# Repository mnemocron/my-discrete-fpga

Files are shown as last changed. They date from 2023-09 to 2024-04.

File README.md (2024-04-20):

# Discrete 7400 logic based FPGA
A custom, modular FPGA architecture simulated in VHDL (GHDL), realized with discrete 7400-logic ICs, layouted on PCB with KiCAD and programmed through an abstraction layer via Arduino.

---

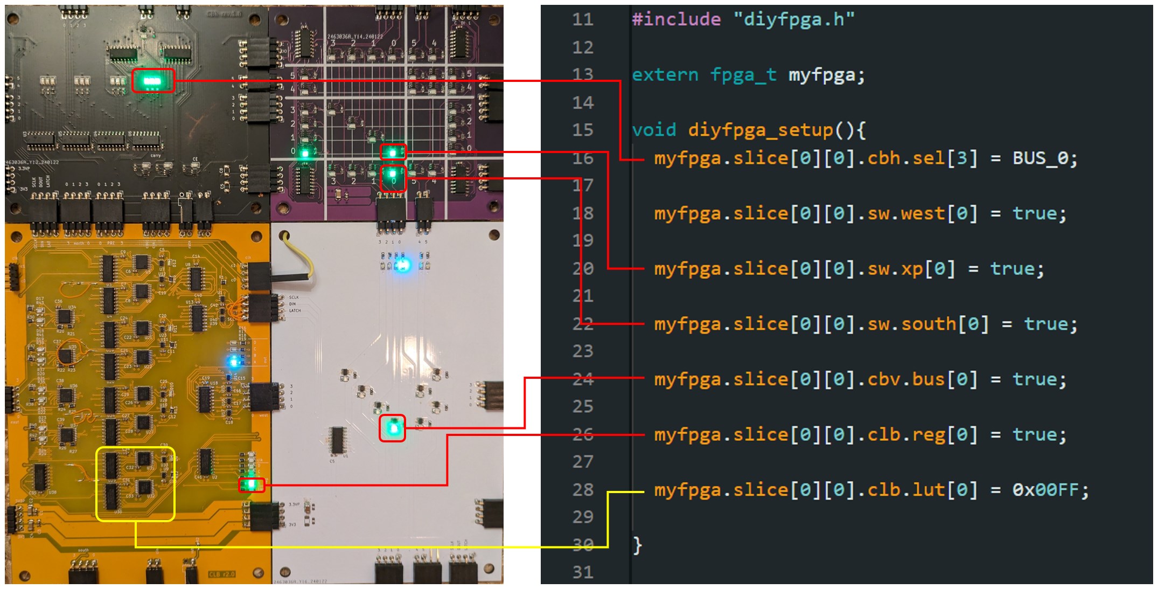
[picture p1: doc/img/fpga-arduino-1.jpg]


Read the full thorugh process and many explanations on my blog: 
[mnemocron.github.io](https://mnemocron.github.io/2023-12-08-DIY-FPGA-diary-0/)

## Motivation

> Why build arguably the worst FPGA ever?

Ever since building Ben Eaters [8 bit CPU](https://eater.net/8bit) myself, I wanted to build something even crazier.
The 8 bit CPU is arguably the worst CPU ever built - but it is a fantastic educational example.
And that is the case for the **4 bit FPGA**. It is a purely educational side project that boosted my knowledge about FPGA architecture, VHDL design and verification. Without further ado, here it is.

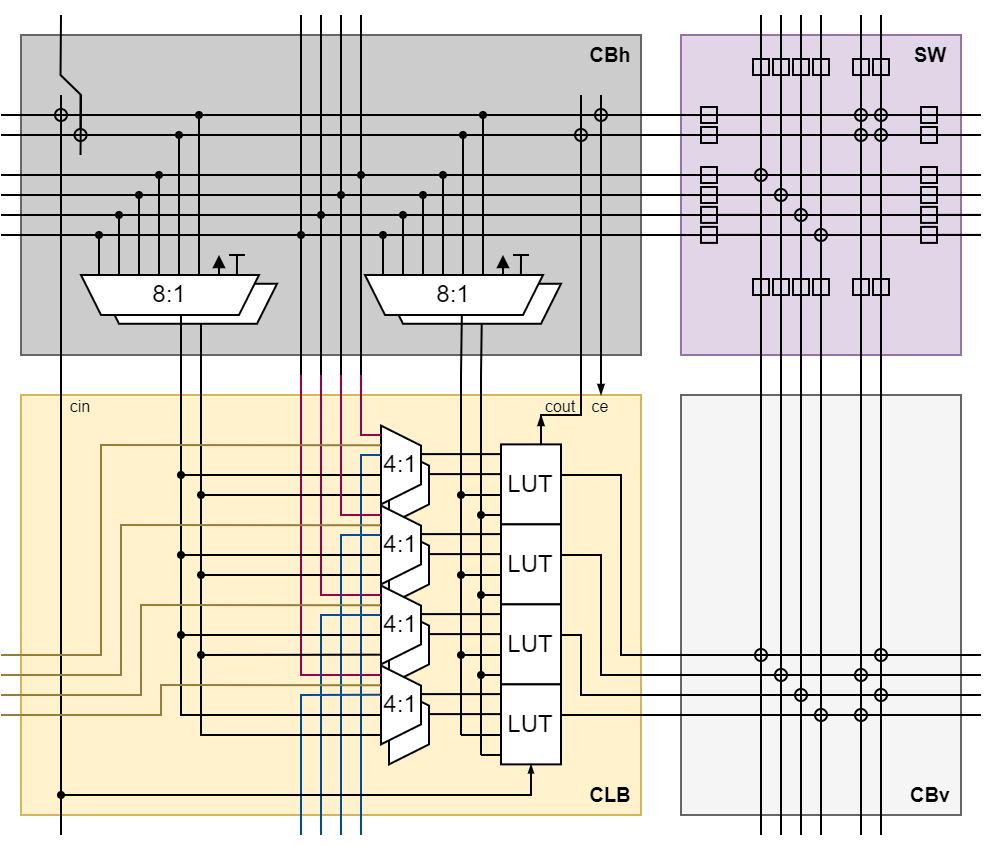
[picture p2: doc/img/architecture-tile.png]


## Build Process

The actual part list is WIP. Expected material cost are approximately 50 USD per assembled tile (4:4 bit LUT with interconnect).

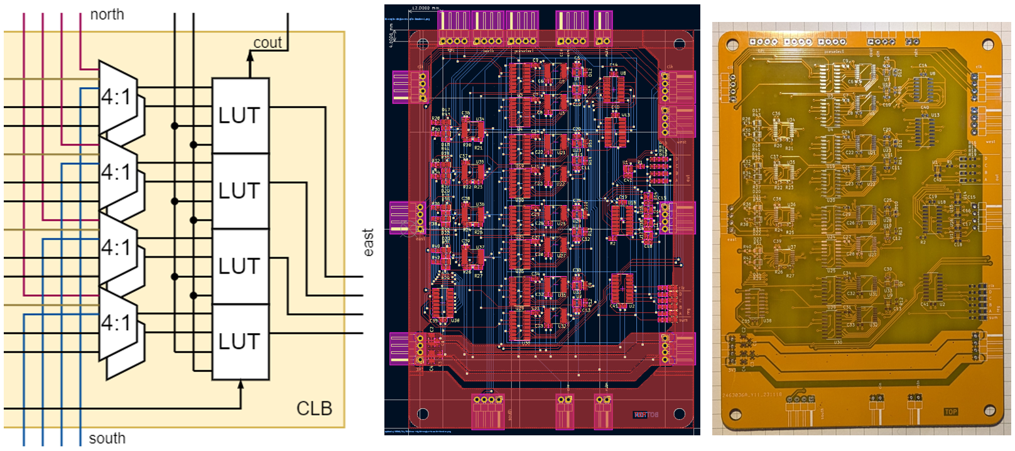
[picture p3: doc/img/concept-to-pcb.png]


---

## Start Here!

Do you want to build this FPGA yourself? Great! Everything, I made regarding this project is in this repository.

To understand the architecture start with `./architecture` or read about it on my blog.
Next, you may dive into the VHDL simulations in `./vhdl` and try out a few things.
Head straight to the `./vhdl/test` directory to see examples with the full FPGA architecture (instead of sub units).

- `./architecture` contains conceptual draw.io block diagrams
- `./doc` contains images, notes and tools that may be helpful
- `./ihdl` (WIP) contains ideas and concepts for a "compiler"
- `./kicad` contains **schematics and PCB files** for KiCAD 7.0
- `./sketch` contains Arduino code for testing of assembled PCB hardware and **abstraction layer in C**
- `./vhdl` contains models for 74xx ICs and the **full FPGA architecture for simulation**

---

## "Assemble" code to map onto the FPGA in Arduino

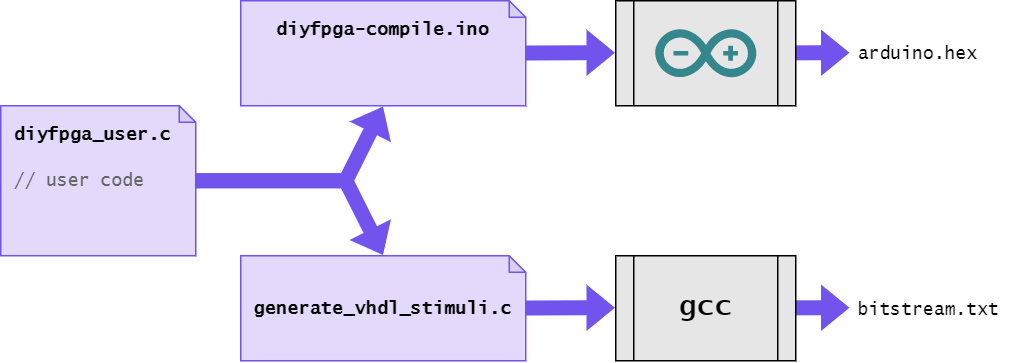
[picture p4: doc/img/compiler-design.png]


---

## Inspiration & Honorable Mentions

### Build an 8-bit computer from scratch

> I built a programmable 8-bit computer from scratch on breadboards using only simple logic gates. I documented the whole project in a series of YouTube videos and on this web site. Watch this video for an introduction:

on [eater.net](https://eater.net/8bit)

### Build your own FPGA

> Building a microcontroller or CPU out of discrete logic is a popular hobbyist pursuit, and it serves a useful purpose: building a CPU from scratch teaches you a lot about CPU architecture and tradeoffs; it's an interesting and instructive exercise. So, I wondered, wouldn't building an FPGA out of discrete logic be similarly educational? 

on [Nick's Blog](http://blog.notdot.net/2012/10/Build-your-own-FPGA)

on [Hackaday](https://hackaday.com/2012/11/01/discrete-fpga-will-probably-win-the-7400-logic-competition/)

### Princeton Regonfigurable Gate Array

> Build your own FPGA Chip or embedded FPGA IP with Python, and enjoy a fully open-source, auto-generated CAD flow specifically for your custom FPGA.

on [github](https://github.com/PrincetonUniversity/prga)

on [princeton.edu](http://parallel.princeton.edu/prga/)

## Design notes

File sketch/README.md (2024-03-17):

# Arduino Sketches 

to test the PCBs

for Arduino Uno

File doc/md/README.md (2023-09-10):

# 4 bit FPGA - Documentation

---

Immagine a gigantic array of breadboards. Each breadboard has a selection of digital circuit chips like XOR, AND and NOT gates plugged in, all waiting to be connected.
Whatever digital function we can come up with, we can map to those basic gates. And we can then use our bag of jumper cables to connect everything the way we need it to be.
That is an FPGA.
Except that the logic functions are look up tables (LUT) and the cables are the interconnect.
To make the timing of the signals deterministic, registers (D-type flip flops) are added to make it a clocked system.
That is all you need to build an FPGA: LUTs, interconnect and registers.

However, modern FPGA chips have many more features built in to implement frequently used digital operations more easily.
This ranges from the carry chain addon to LUTs, multiply-accumulate blocks (DSP slice) all the way to fully realized CPUs, AI cores and high-speed serial transceivers.

The first step in designing an FPGA is to have a sense of what applications might be realized on it.
It may require a CPU to do networking and graphical user interfaces or be targeted at radio frequency signal acquisition, processing and generation.
For this tiny FPGA project, a few applications should be able to run on it including:

- 4 bit or 8 bit counter
- 4 bit addition
- clock domain crossing

Nevertheless, the architecture shall remain modular to expand it with more features later on.
The initial architecture consists of:

- Configurable Logic Block (including the LUT)
- Interconnect blocks

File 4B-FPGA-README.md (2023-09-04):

# 4Bit-FPGA

---

## Application Use Cases

- 4-bit counter
- 4-bit counter with GPIO output
- 4-bit counter with 7-segment converter
- 4-bit counter with 7-segment hard-IP
- 4 + 4 bit adder from external GPIO input
- "roll a dice" with 2-clock domains, double flop synchronization, button press, and edge detection

something with RAM
- timer which stores counter value in BRAM, readout by cycle-clicking again
- toggle on RAM full/empty bits

CPU
- 

hard-IP
- BCD to 7-segment

cpu = custom instruction

### 4:1 CLB/LUT

4 bits is the ideal compromise for the planned application use cases.
4 bits are used in BCD numbering and is a reasonable amount for a counter application.

- clk_in[1:0]
- clb_in[3:0]
- clb_out

- conf_miso
- conf_mosi
- conf_sclk
- conf_ltch

conf bits
[15 :  0] = LUT content
[16] clk select

---

Shift Register 74HC595D
https://www.digikey.ch/de/products/detail/toshiba-semiconductor-and-storage/74HC595D/5879984

MUX 8:1 74HC151D
https://www.digikey.ch/de/products/detail/toshiba-semiconductor-and-storage/74HC151D/6198926

MUX 2:1 NC7SV157P6X
https://www.digikey.ch/de/products/detail/onsemi/NC7SV157P6X/1049166

D Flip-Flop 1 bit 74AHC1G79GW
https://www.digikey.ch/de/products/detail/nexperia-usa-inc/74AHC1G79GW-125/1229497

Signal Switch 1:1 
https://www.digikey.ch/de/products/filter/logik/signalumschalter-multiplexer-decoder/743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

https://www.digikey.ch/de/products/filter/schnittstelle/analoge-schalter-multiplexer-demultiplexer/747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

GPIO Buffer
https://www.digikey.ch/de/products/detail/toshiba-semiconductor-and-storage/74VHCV245FT/5977737

---

Videos

1. Breadboard FPGA Project overview

"the shittiest FPGA ever created"

DIY FPGA with 24 CLB-LUT

2. Configurable Logic Blocks - 4-bit FPGA
- basics of digital logic
- history of FPGAs
- configurable logic functions
- look up table
- SRAM bits as configuraion

3. Interconnect and Routing - 4-bit FPGA
- connecting the LUT
- freedom vs. complexity
- bit shift operation = "free"
- reference current modern FPGA switch boxes
- argument for architecture choice

4. I/O driver - 4-bit FPGA

4. Phase Locked Loop (PLL) - 4-bit FPGA
- clock generation and division

5. System Controller
- bitstream loading
- arduino board

6. Building the FPGA - 4-bit FPGA
- explain modern FPGA architecture (columns)
- 

7. Programming the Field Programmable Gate Array - 4-bit FPGA
- bitstream modification
- upload of bitstream

### Applications

1. Test Application: 4-bit counter - 4-bit FPGA
- 4-bit counter LUT programming
- interconnect routing
- GPIO configuration
- BCD to 7-segment decoder
- change to 8-bit
- explain why 8-bit CPU is "impossible"
- explain the scale and cost of this platform

2.

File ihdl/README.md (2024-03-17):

# iHDL Language Specification

---

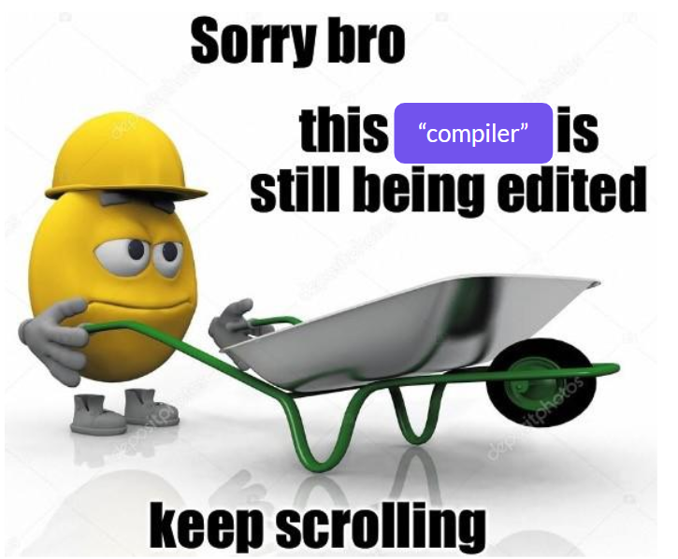
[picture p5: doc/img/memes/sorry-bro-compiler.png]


---

## General Rules

### Assignments

#### Static Assignment `:=`

`<var> := <const>;`

Assigning location properties or other static features that can be enabled or disabled.

Example, location constraint:
> `loc := "A1";`

#### Synchronous Assignment `<=`

`<port> <= <expr>;`

Synchronous assignment of a boolean function of input ports to an output port.
Using the synchronous assignment will evoque a D-type flip flop in the output signal to the specified port.

Example,
> `q0 <= b0 and b1;`

#### Asynchronous Assignment `

`<port> = <expr>;`

Asynchronous assignment of a boolean function of input ports to an output port.
Using the asynchronous assignment will output the evaluated signal directly to the specified port without a register stage.

Example,
> `q0 = b0 and b1;`

---

## Objects

The following objects can be instantiated.

### CLB Slice `slice`

#### Input Ports

- bus inputs (north) `b0`,`b1`,`b2`,`b3`
- sum inputs (north) `n0`,`n1`,`n2`,`n3`
- sum inputs (south) `s0`,`s1`,`s2`,`s3`
- lut expansion inputs `x0`,`x1`,`x2`,`x3`
- highway inputs (north) `h0`,`h1`

#### Output Ports

- bus outputs (east) `b0`,`b1`,`b2`,`b3`
- highway outputs (east) 

#### Internal signals

The following signals are optional to be assigned to the highway signals `h0` and `h1` when using the slice in the adder mode.

- sum carry input `cin`
- sum carry output `cout`

#### Options

- location constraint `loc`
- 

#### Operators

Valid operators are
- `and`
- `or`
- `not`
- `xor`
- `+` (arithmetical sum)

Valid values besides inputs are 
- `0` zero / GND
- `1` one / Vcc

## Error Types

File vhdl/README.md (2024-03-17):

# VHDL Simulation
---

## Run Simulation

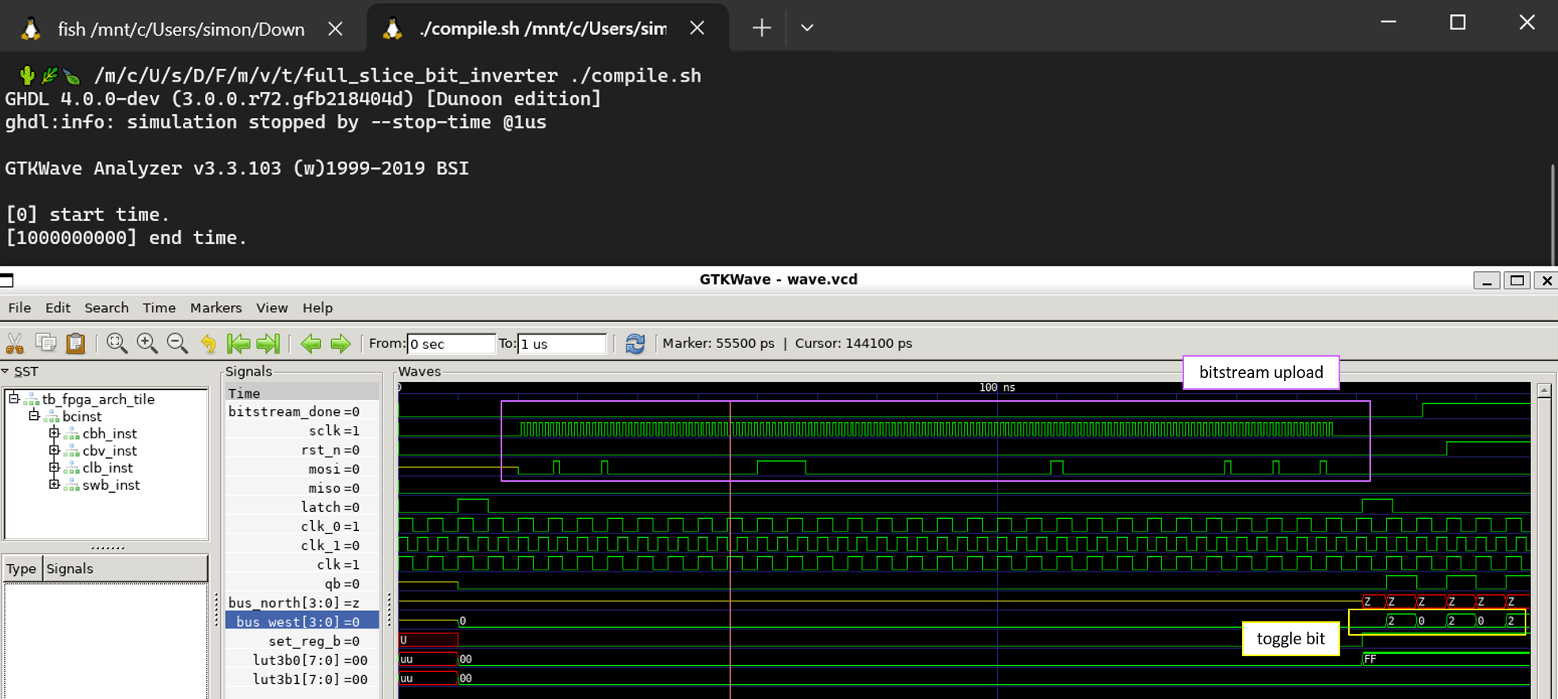
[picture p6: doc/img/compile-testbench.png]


The VHDL simulation consists of separate modules/units/entities for each 74xx chip.
Using the 74xx models, the higher level CLB, CBh, CBv and SW entities can be constructed.
Those four (CLB, CBh, CBv, SW) form the top level entity: a tile (`arch_tile`) which is one modular building block of the FPGA.
Multiple tiles in a 2D matrix form the full FPGA - this is not yet implemented in simulation.

Each entity folder contains a `compile.sh` which runs the unit testbench and opens GTKWave to inspect the waveform.
The testbenches are not self-checking although some of them contain assert statements.

This codebase was tested with the following setup:
- GHDL 4.0.0-dev (3.0.0.r72.gfb218404d)
- GTKWave Analyzer v3.3.103
- on Windows 10 WSL2 (Ubuntu 20.04.6 LTS focal on Windows 10 x86_64)

---

## FPGA modules

### Arch Slice (top level)

- Entity: `arch_slice`
- Dependencies: 
	+ `clb_slice`
	+ `sw_box`
	+ `connection_box_horizontal`
	+ `connection_box_vertical`
- Version: ``
- Tests: 
- Comments: see the `/tests` directory for various bitstreams that are uploaded to the `arch_slice` testbench

### CLB

- Entity: `clb_slice`
- Dependencies: 
	+ `sr_74xx595`
	+ `ff_74xx175`
	+ `mux_74xx151`
	+ `mux_74xx153`
	+ `mux_74xx157`
	+ `mux_74LVC1G157`
	+ `xor_74xx86`
- Version: `1.0.0`
- Tests: ✅
- Comments: simple tests only

### CBv

- Entity: `connection_box_vertical`
- Dependencies: 
	+ `sr_74xx595`
	+ `cbox`
- Version: `1.0.0`
- Tests: ✅
- Comments: only checking for multiple drivers inside entity itself

### CBh

- Entity: `connection_box_horizontal`
- Dependencies: 
	+ `sr_74xx595`
	+ `cbox`
	+ `mux_74xx151`
- Version: `1.0.0`
- Tests: -
- Comments: no self checking testbench

### SW box

- Entity: `sw_box`
- Dependencies: 
	+ `sr_74xx595`
	+ `digital_switch`
	+ `newsw`
- Version: ``
- Tests: -
- Comments: 

---

### MUX 8:1 74xx151 / 74xx251
- Single 8-Input Multiplexer
- for LUT3 elements

### MUX 4:1 74xx153 / 74xx253
- Dual 4-Input Multiplexer
- CLB tile input[3:2] select

### MUX 2:1 74xx157 / 74xx257
- Quad 2-Input Multiplexer
- sum output selector (`set_sum`)

### MUX 2:1 74-1G157
- Single 2-Input Multiplexer
- LUT4 element, set_reg, carry_mux

### D-type Register 74xx175
- Quad D-type Flip Flop

### XOR 74xx86
- Quad 2-Input XOR
- sum

### Shift Register 74xx595
- 8-bit shift register with latch
- LUT3 memory, configuration registers

---

| IC | simulation |
|:---|:---|
| 74xx157 | ✅ |
| 74xx153 | ✅ |
| 74xx151 | ✅ |
| 74xx175 | ✅ |
| 74xx595 | ✅ |
| 74xx86  | ✅ |
| 74_1G157 | ✅ |

---

## Interconnect Simulation

- use `std_logic` not `std_ulogic` because of "multiple drivers"

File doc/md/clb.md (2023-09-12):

# Configurable Logic Block (CLB)

---

A look up table has to have at least 2 inputs and one output.
To create more useful functions, more inputs are added.
One could create a LUT with 16 inputs to cover logic operations that depend on up to 16 input variables.
Such functions are rare and many of the inputs (and subsequently area on the silicon) would be wasted.
There is a balance regarding the maximum number of inputs which is somewhere between 4 and 6 inputs.
Various FPGA vendors have different approaches to it.

## Number of Inputs / Outputs

The number of outputs is usually 1. Some vendors however allow a 6:1 LUT to be configured as a 5:2 LUT instead, offering 2 outputs taking the same 5 signals as inputs.
This FPGA does not have a configurable number of outputs.
It would increase the complexity of the output routing and interconnect.

## CLB Architecture

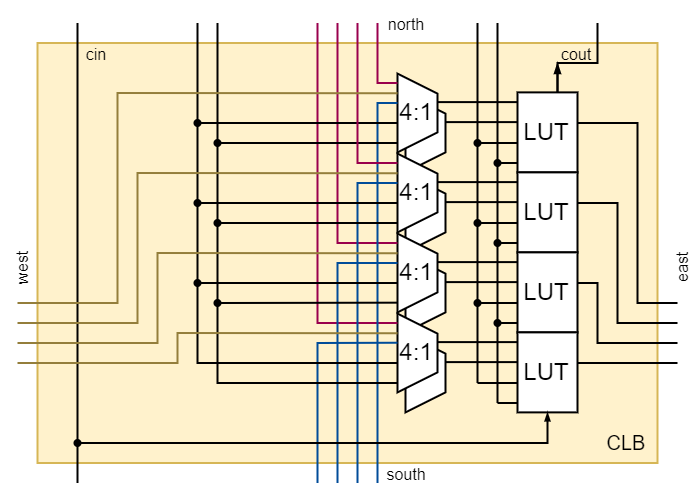
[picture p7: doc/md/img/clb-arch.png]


### Look Up Table (LUT) 

#### LUT3 / LUT4

To create useful applications within a reasonable usage of hardware area a 4 input LUT is proposed.
LUTs are most effectively implemented using a multiplexer which uses the LUT input signals as the address signals.
Since `2^4` input multiplexers are less common than `2^3` input multiplexers, the LUT4 is composed of two LUT3 primitives.
Here, a feature that configures the LUT4 (4:1) into a 2 output LUT3 (3:2) could be implemented. 
However, since there are 4 LUT4 instances in one CLB and because the output bus architecture only has 4 signals it makes no sense to have 8 outputs per CLB.

#### LUT Bundle (Slice / Block)

Multiple LUTs are usually bundeled within a block that is then called a configurable logic block (CLB).
(Sometimes LUTs are bundeled in slices and slices are bundeled in a block)
The CLB adds additional features and configurable options between the LUTs inside that block.
The most common feature is the carry chain.
One feature that is added to this FPGA is the carry chain.

### Connection Ports

The CLB requires input ports and output ports. 
A helpful simplification in the overall FPGA architecture is to define a direction in which the signals travel.
In this FPGA it is from west to east and in a weaker sense from north to south.

The CLB has four bus input ports:
- 4 bit bus north
	+ this is one of the 4 bit inputs for the adder mode
- 4 bit bus south
	+ this is one of the 4 bit inputs for the adder mode
- 4 bit bus west
	+ this bus is the direct output of the west CLB
- 4 bit preselected input
	+ each bit is preselected to any one signal of the bus
	+ allows for bit position changes (shift / rotate / flip)

The CLB has one 4 bit output port.

The CLB has 2 carry in signals and one carry out signal.
- North `cin` 
	+ can be activated in the north connection box
- South `cin` 
	+ can be activated in the north connection box of the south CLB

### Input Multiplexers 4:1 (post select) `insel*`

Under normal circumstances, all 4 LUTs inside the CLB receive the same 4 (preselected) input signals.
Depending on the individual LUT configuration, 4 different output signals are possible.
When performing the addition operation, this configuration of inputs is insufficient since it only allows for 2 + 2 bit additions.
Therefore, each LUT has 2 4:1 multiplexers before their `A2` and `A3` inputs.

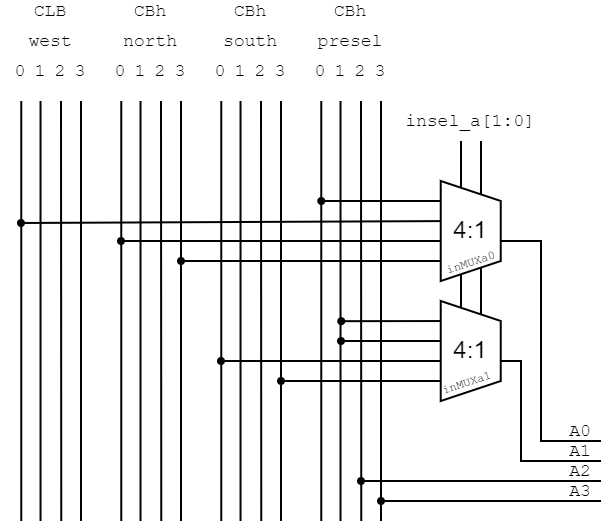
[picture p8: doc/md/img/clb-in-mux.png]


The 4-way input multiplexers have 4 modes.

| `insel_*[1:0]` | mode |
|:---|:---|
| `00` | regular preselect input `INMODE_PRESEL` |
| `01` | expanded LUT input `INMODE_EXPIN` |
| `10` | sum mode `INMODE_SUM` |
| `11` | sum mode bit reversed `INMODE_SUM_REVERSE` |

### Carry Look Ahead Adder

Performing additions in hardware requires a number of one bit full-adder circuits equal to the bit length of the largest number to be added.
A regular full adder can add 1 + 1 bits + 1 carry bit.
The carry bit is propagated from the LSB to the MSB.
A calculation is complete when the MSB of the sum is calculated which can only happen after the previous bits have ben sequentially calculated.

One way this could have been implemented is shown in the following picture.
It has been implemented this way in the other discrete FPGA on [Nick's Blog](http://blog.notdot.net/2012/10/Build-your-own-FPGA).
The LUT would be configured in a dual 3:2 LUT (instead of the regular 4:1) where one output is the sum output and the other output is the propagated carry.
This solution complicates the input multiplexin would add another 2:1 multiplexer to the proposed architecture draft.

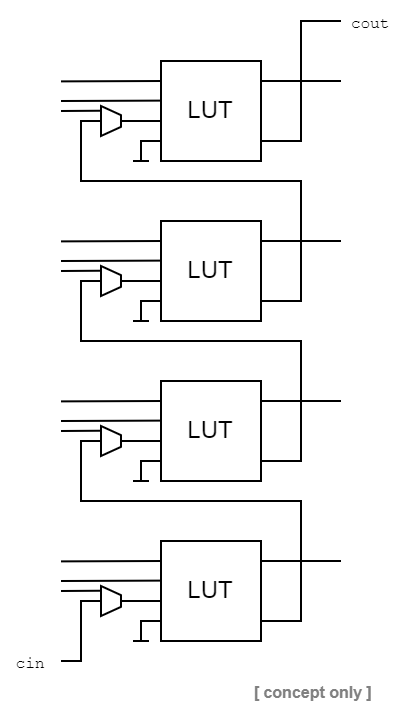
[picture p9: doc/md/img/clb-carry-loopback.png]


There is one substantial drawback when using long carry chains. 
The carry chain is the (timing) critical path.
For FPGAs there exist improvements to this problem to improve (timing) performance.
Xilinx FPGAs solve the critical path problem using a __Carry Look Ahead Adder__ as shown in the next picture. 
The carry bit is calculated in advance and selected based on the result of the current sum bit.

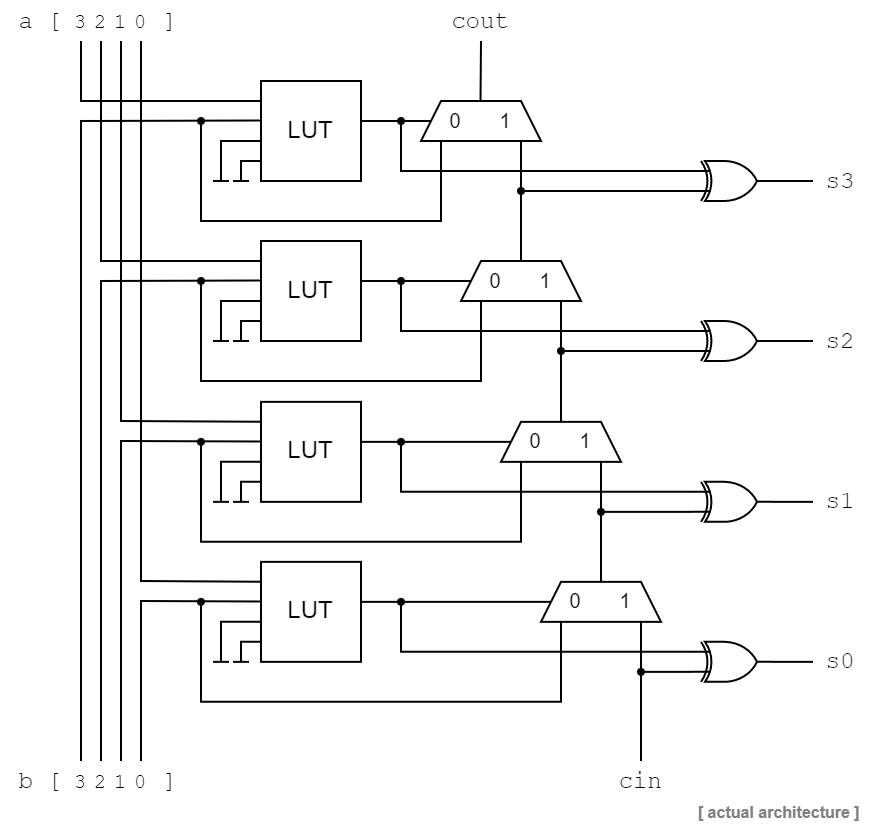
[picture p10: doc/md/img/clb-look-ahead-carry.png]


An example calculation of `13 + 5 = 18` is shown in the following figure.

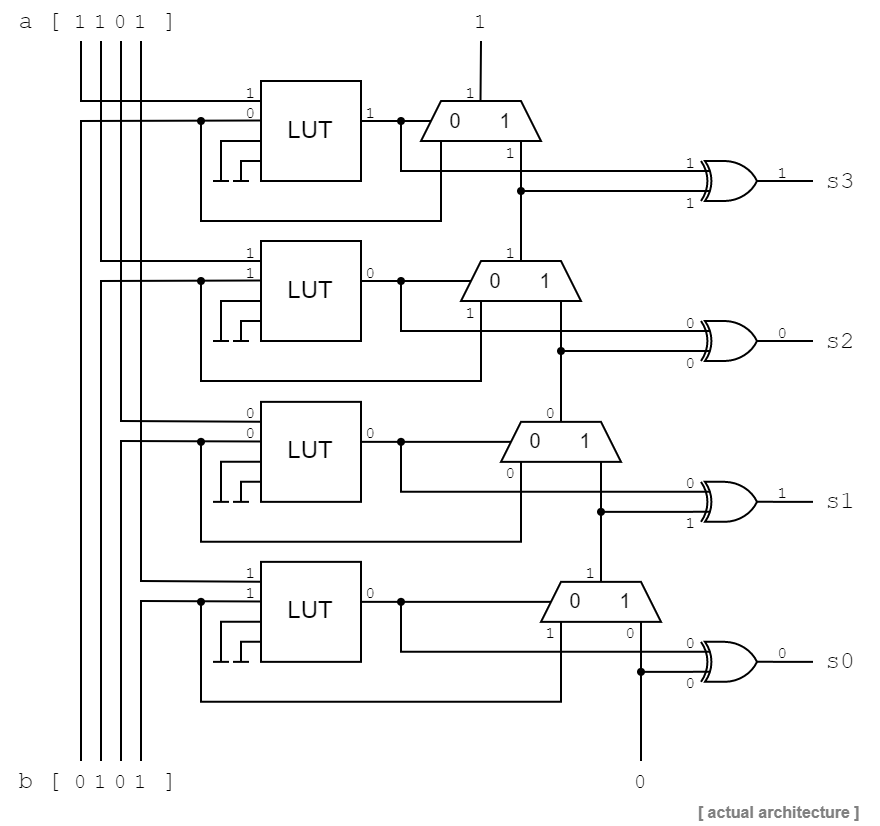
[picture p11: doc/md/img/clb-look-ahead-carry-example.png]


### Final LUT4 Architecture

The implemented LUT4 architecture is shown below. It features:
- LUT4 composed of 2x LUT3 instances
- __look ahead carry__ (optional sum mode)
- 4:1 input options for 2 of the 4 inputs
- optional output register (D-type flip flop)

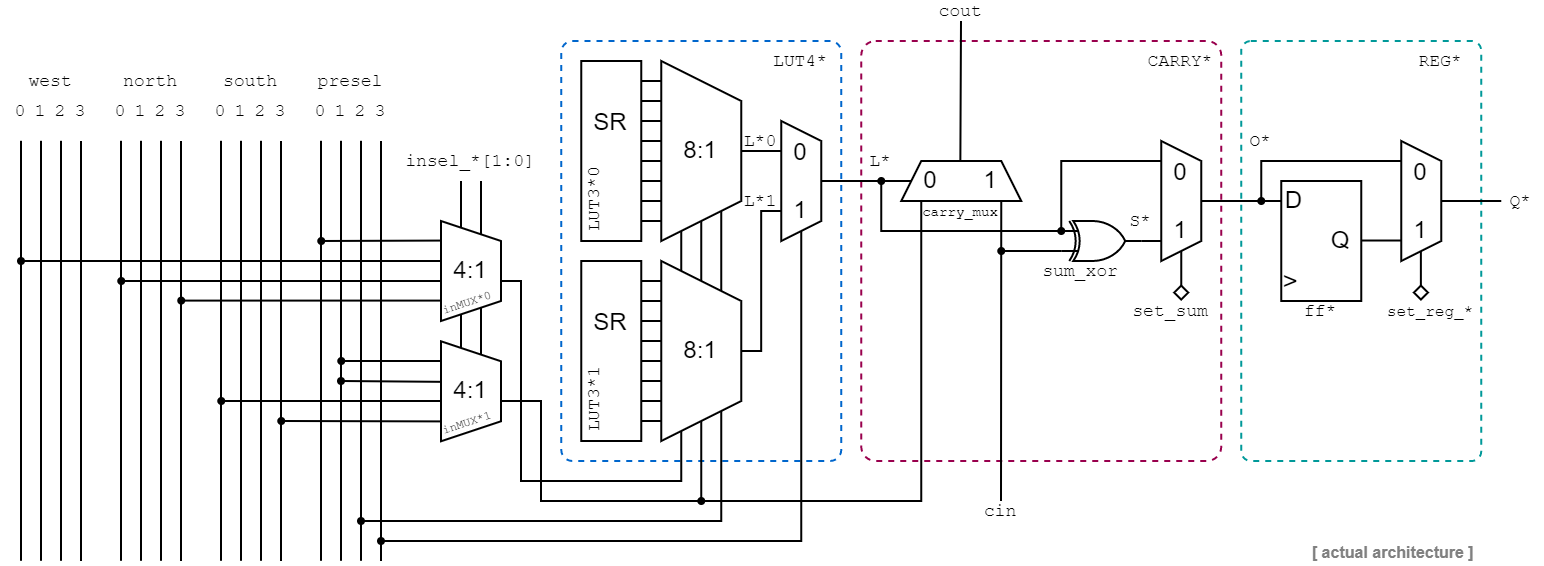
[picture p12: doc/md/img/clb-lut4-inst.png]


---

## 74** Part List

- `74**151`/ (`74**251` with tri-state output)
	+ single 8-input multiplexer
- `74**595`
	+ 8 bit shift register with latch
	+ used as one LUT3 memory
	+ used as configuration memory
- `74**153` / (`74**253` with tri-state output)
	+ dual 4-input multiplexer
	+ used as input selector
- `74**86`
	+ quad 2-input XOR
	+ used for sum calculation
- `74**157` / (`74**257` with tri-state output)
	+ quad 2-input multiplexer
	+ used for the LUT4 output selection (LUT output vs. sum output)
- `74**175`
	+ quad D-type flip flop
- `74**1GG157`
	+ single 2-input multiplexer
	+ used to combine 2x LUT3 instances to LUT4
	+ used for carry chain

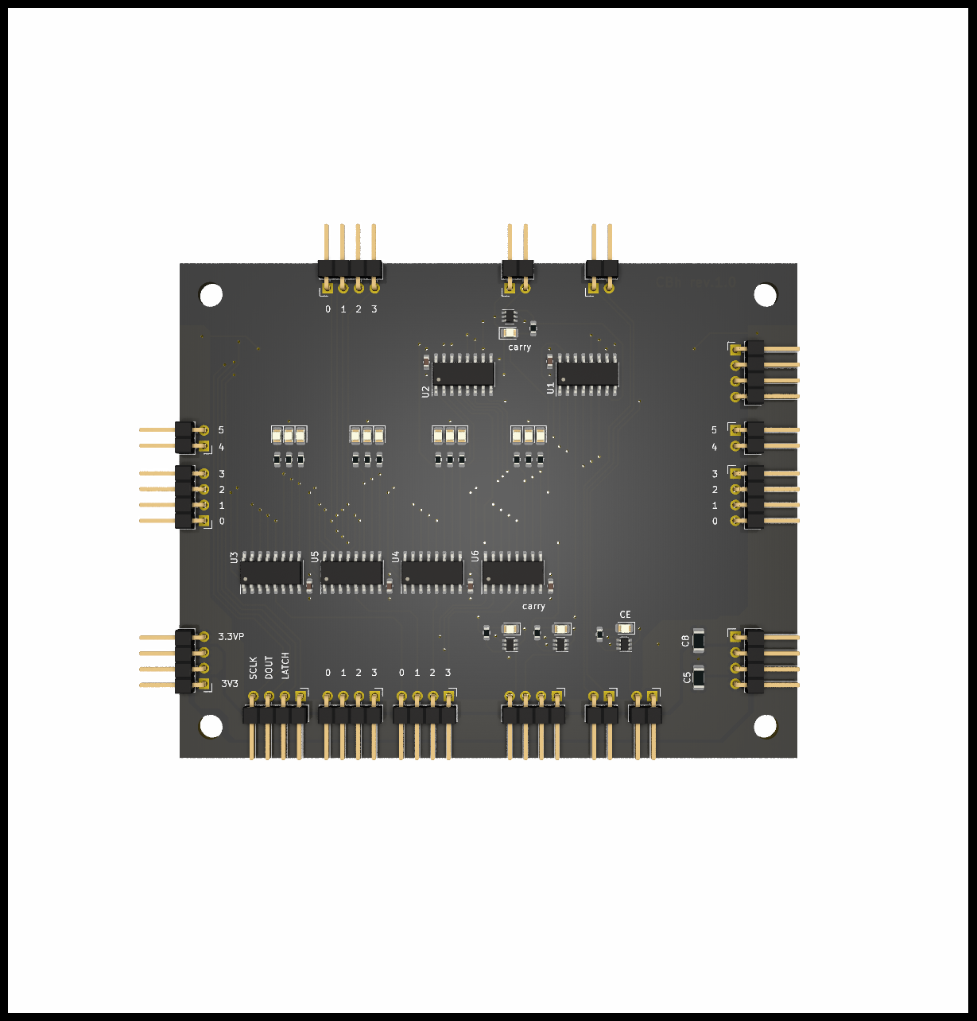
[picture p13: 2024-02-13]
doc/img/render/myFPGA-CBh.png

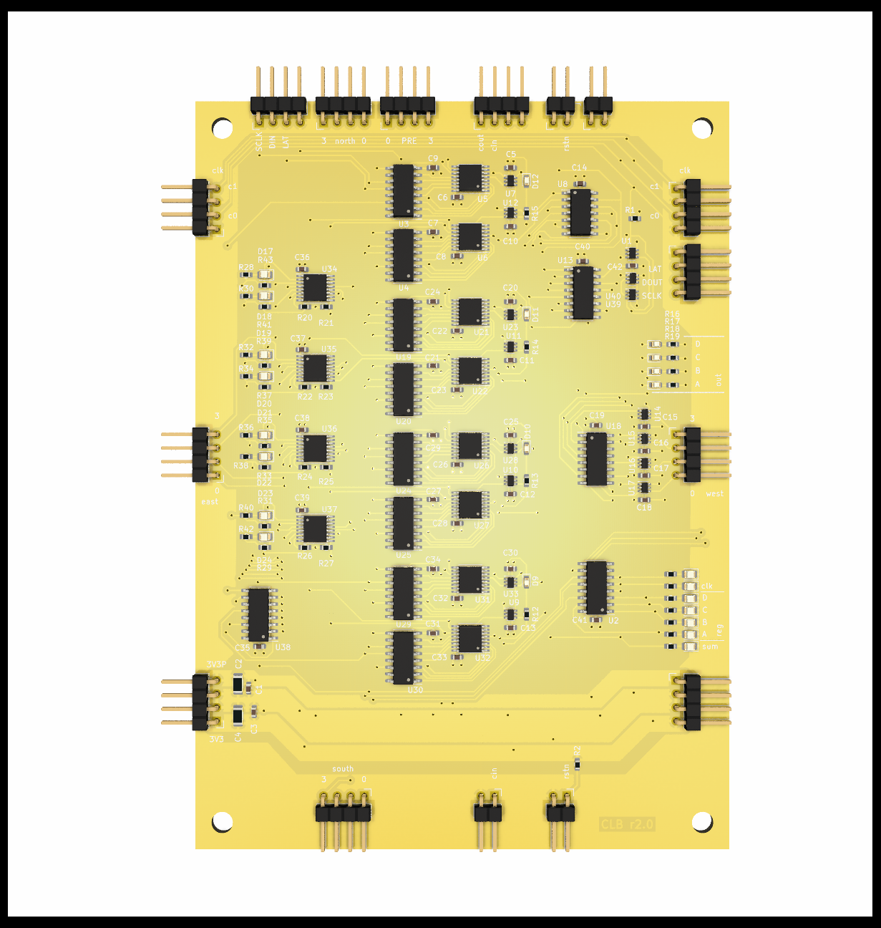
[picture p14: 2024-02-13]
doc/img/render/myFPGA-CLB-slice.png

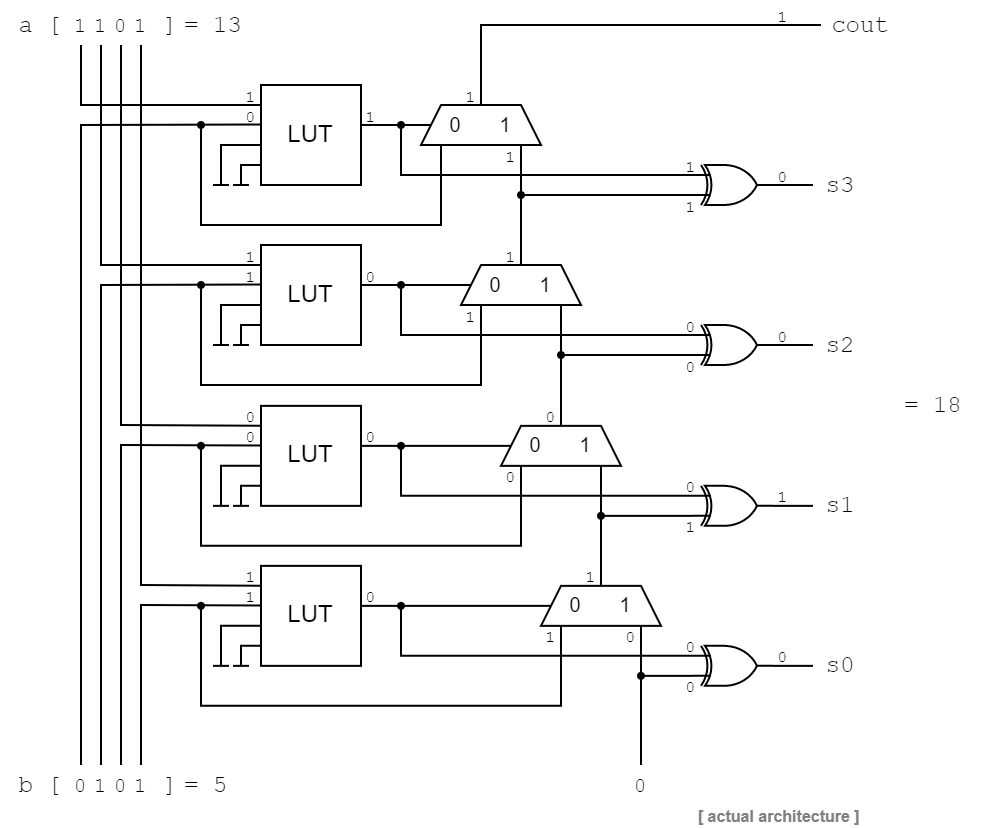
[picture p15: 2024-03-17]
doc/img/clb-look-ahead-carry-example.png

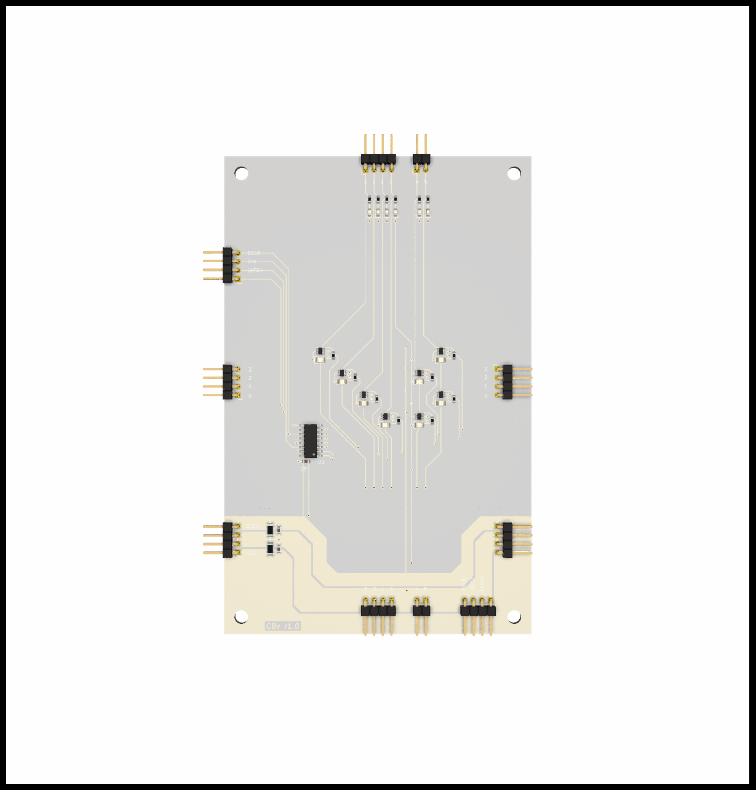
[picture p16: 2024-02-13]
doc/img/render/myFPGA-CBv.png

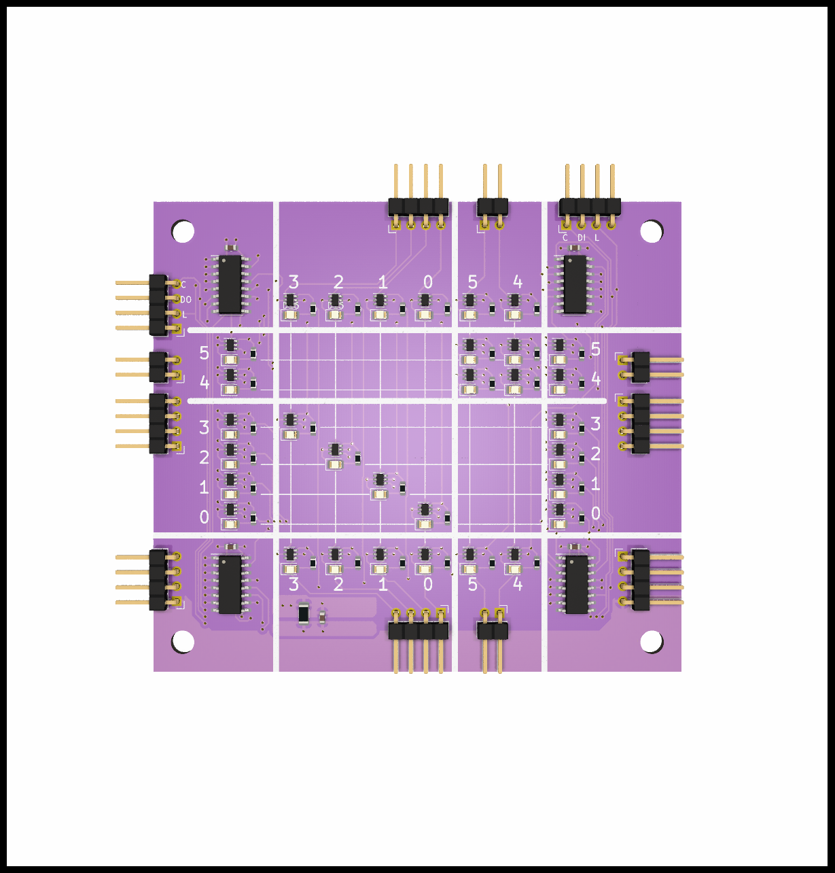
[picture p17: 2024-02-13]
doc/img/render/myFPGA-SW-box.png

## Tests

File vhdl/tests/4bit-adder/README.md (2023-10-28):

# Simple Bit Inverter

---

using LUT B

will output `clb_slice.Qb` --> `connection_box_vertical.bus_west[1]`

- `connection_box_vertical.xpoint_1_en = 1` (6)

will output `connection_box_vertical.bus_north[1]` --> `sw_box.bus_south[1]`

- `sw_box.sw_9 = 1` (126)
- `sw_box.sw_17 = 1` (118)
- `sw_box.xpoint_1 = 1` (134)

will output `sw_box.bus_west[1]` --> `connection_box_horizontal.bus_east[1]`

let's just pick preselect 2 and leave all other preselect to 0 (GND).

- `connection_box_horizontal.presel_2[0] = 0` 
- `connection_box_horizontal.presel_2[1] = 1` (93)
- `connection_box_horizontal.presel_2[2] = 1` (94)

will output `sw_box.preselect[2]` --> `clb_slice.cb_pre[2]`

`presel[2]` affects the LUT3 stage. implement an inverter where all other inputs are `X` (don't care)

- `insel`

- `LUT3b1[0] = 1` (52)
- `LUT3b1[1] = 1` (53)
- `LUT3b1[2] = 1` (54)
- `LUT3b1[3] = 1` (55)

- `LUT3b0[0] = 1` (44)
- `LUT3b0[1] = 1` (45)
- `LUT3b0[2] = 1` (46)
- `LUT3b0[3] = 1` (47)

- `set_reg_b = 1` (76)

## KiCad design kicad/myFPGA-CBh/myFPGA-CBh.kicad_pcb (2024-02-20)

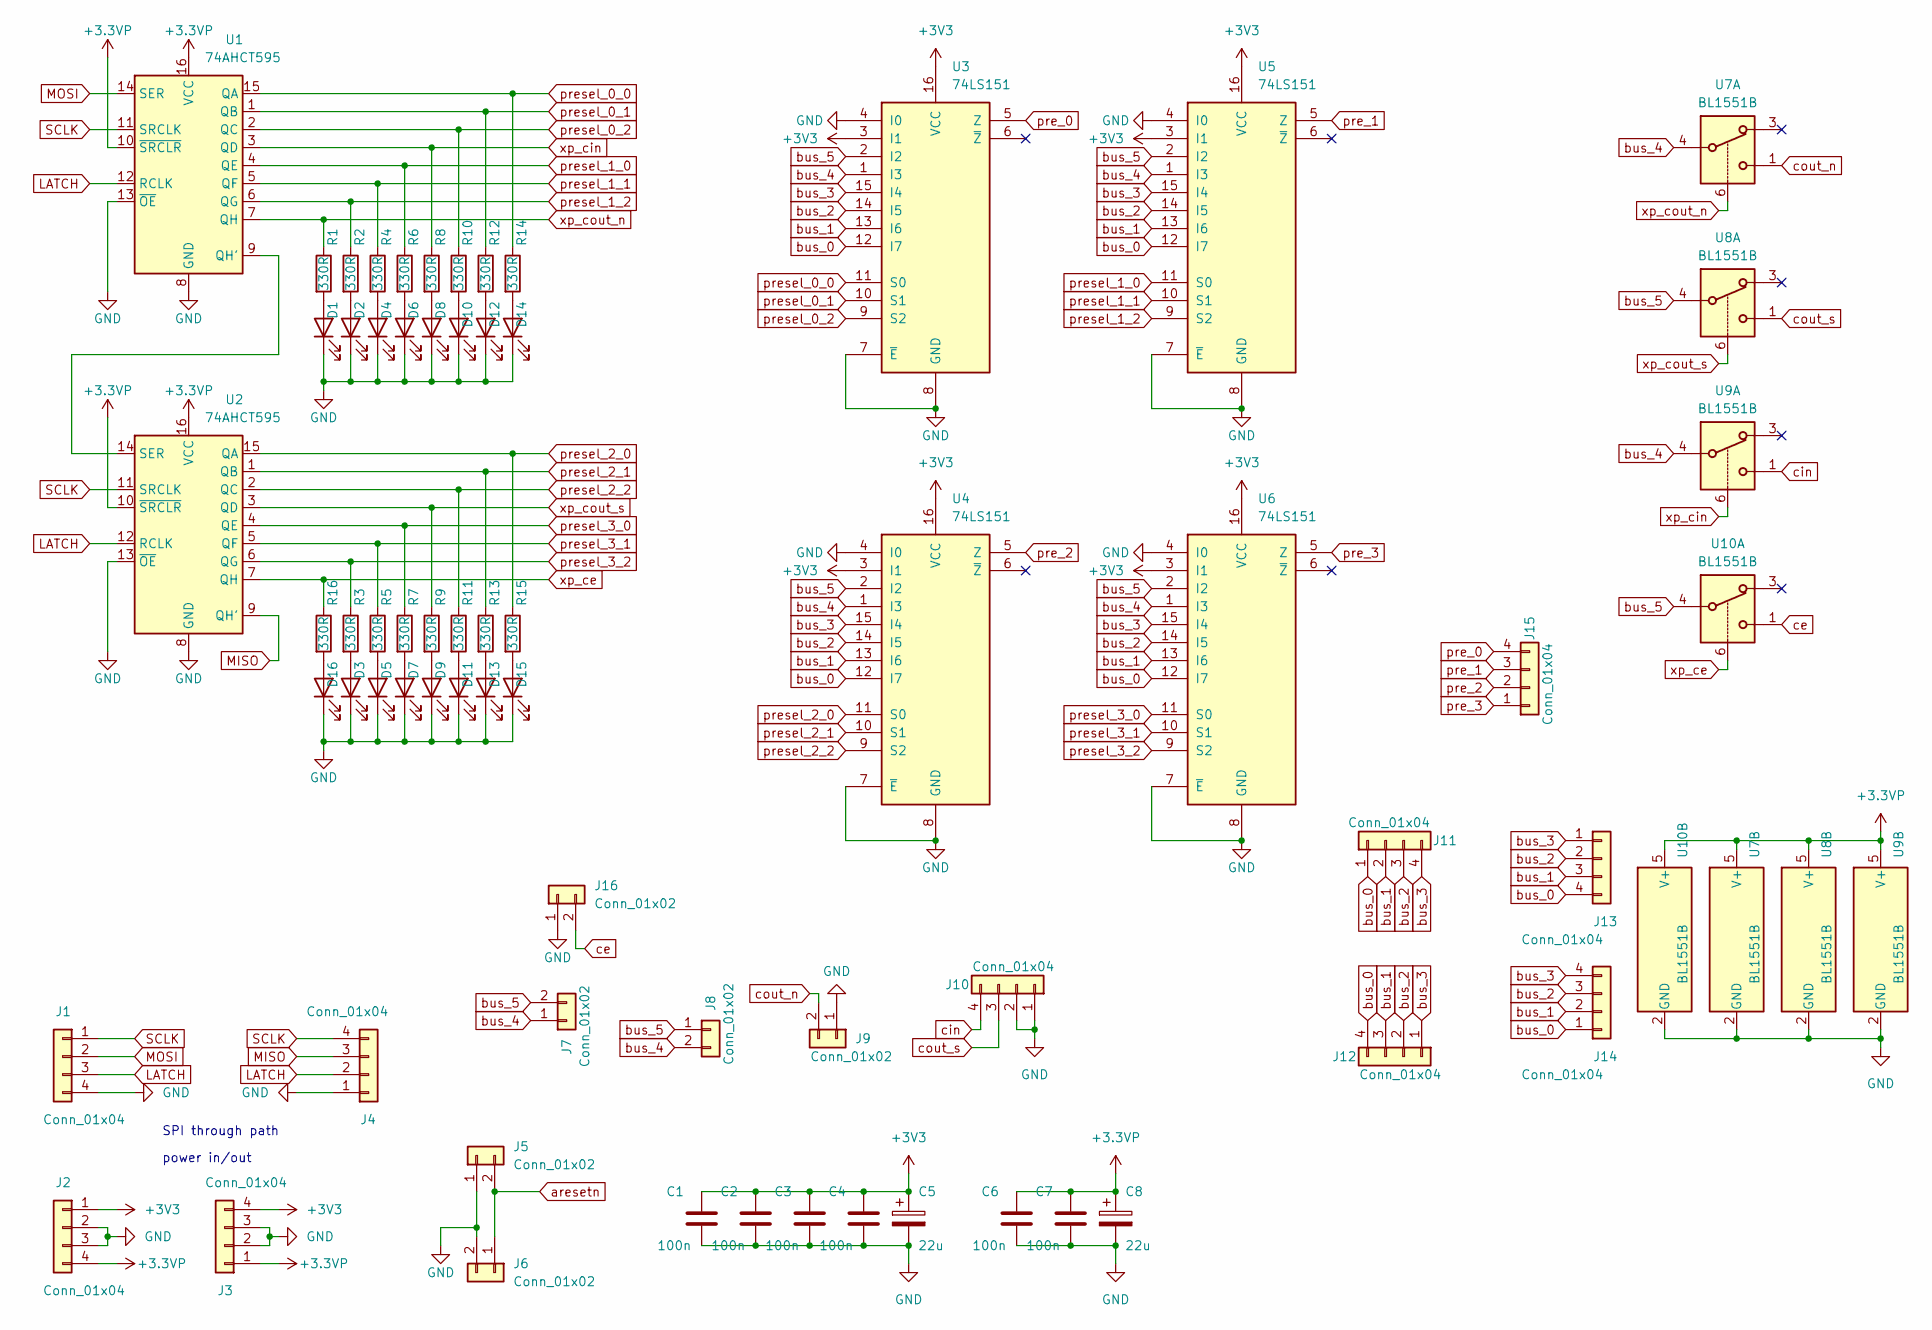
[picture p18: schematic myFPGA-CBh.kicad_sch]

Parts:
C1, C2, C3, C4, C6, C7: 100n; C_0603_1608Metric; Voltage 50; Part Nr. CC0603KRX7R9BB104; JLCPCB Part # C14663
C5, C8: 22u; R_1206_3216Metric; Voltage 25; Part Nr. CL31A226KAHNNNE; JLCPCB Part # C12891
D1, D2, D3, D4, D5, D6, D7, D8, D9, D10, D11, D12, D13, D14, D15, D16: LED (green); LED_0805_2012Metric; Part Nr. C2297; JLCPCB Part # C2297
J1, J2, J3, J4, J10, J11, J12, J13, J14, J15: Conn_01x04; PinHeader_1x04_P2.54mm_Horizontal; Part Nr. do not place; JLCPCB Part # do not place
J5, J6, J7, J8, J9, J16: Conn_01x02; PinHeader_1x02_P2.54mm_Horizontal; Part Nr. do not place; JLCPCB Part # do not place
R1, R2, R3, R4, R5, R6, R7, R8, R9, R10, R11, R12, R13, R14, R15, R16: 330R; R_0603_1608Metric; Part Nr. 0603WAF3300T5E; JLCPCB Part # C23138
U1, U2: 74AHCT595; SOIC-16_3.9x9.9mm_P1.27mm; Part Nr. 74HC595D; JLCPCB Part # C5947
U3, U4, U5, U6: 74LS151; SOIC-16_3.9x9.9mm_P1.27mm; Part Nr. 74HC151DR; JLCPCB Part # C6822
U7, U8, U9, U10: BL1551B; SOT-363_SC-70-6; Part Nr. BL1551B; JLCPCB Part # C2944066

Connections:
+3.3VP: C6.1, C7.1, C8.1, J2.4, J3.1, U1.10 (~SRCLR), U1.16 (VCC), U2.10 (~SRCLR), U2.16 (VCC), U7.5 (V+), U8.5 (V+), U9.5 (V+), U10.5 (V+)
+3V3: C1.1, C2.1, C3.1, C4.1, C5.1, J2.1, J3.4, U3.3 (I1), U3.16 (VCC), U4.3 (I1), U4.16 (VCC), U5.3 (I1), U5.16 (VCC), U6.3 (I1), U6.16 (VCC)
GND: C1.2, C2.2, C3.2, C4.2, C5.2, C6.2, C7.2, C8.2, D1.1 (K), D2.1 (K), D3.1 (K), D4.1 (K), D5.1 (K), D6.1 (K), D7.1 (K), D8.1 (K), D9.1 (K), D10.1 (K), D11.1 (K), D12.1 (K), D13.1 (K), D14.1 (K), D15.1 (K), D16.1 (K), J1.4, J2.2, J2.3, J3.2, J3.3, J4.1, J5.1, J6.2, J9.1, J10.1, J10.2, J16.1, U1.8 (GND), U1.13 (~OE), U2.8 (GND), U2.13 (~OE), U3.4 (I0), U3.7 (~E), U3.8 (GND), U4.4 (I0), U4.7 (~E), U4.8 (GND), U5.4 (I0), U5.7 (~E), U5.8 (GND), U6.4 (I0), U6.7 (~E), U6.8 (GND), U7.2 (GND), U8.2 (GND), U9.2 (GND), U10.2 (GND); also elsewhere on the board
LATCH: J1.3, J4.2, U1.12 (RCLK), U2.12 (RCLK); also elsewhere on the board
MISO: J4.3, U2.9 (QH'); also elsewhere on the board
MOSI: J1.2, U1.14 (SER)
unnamed: D1.2 (A), R1.2
unnamed: D2.2 (A), R2.2
unnamed: D3.2 (A), R3.2
unnamed: D4.2 (A), R4.2
unnamed: D5.2 (A), R5.2
unnamed 11: D6.2 (A), R6.2; also elsewhere on the board
unnamed: D7.2 (A), R7.2
unnamed: D8.2 (A), R8.2
unnamed: D9.2 (A), R9.2
unnamed: D10.2 (A), R10.2
unnamed: D11.2 (A), R11.2
unnamed: D12.2 (A), R12.2
unnamed: D13.2 (A), R13.2
unnamed: D14.2 (A), R14.2
unnamed: D15.2 (A), R15.2
unnamed: D16.2 (A), R16.2
unnamed: U1.9 (QH'), U2.14 (SER)
SCLK: J1.1, J4.4, U1.11 (SRCLK), U2.11 (SRCLK); also elsewhere on the board
aresetn: J5.2, J6.1; also elsewhere on the board
bus_0: J11.1, J12.4, J13.4, J14.1, U3.12 (I7), U4.12 (I7), U5.12 (I7), U6.12 (I7)
bus_1: J11.2, J12.3, J13.3, J14.2, U3.13 (I6), U4.13 (I6), U5.13 (I6), U6.13 (I6)
bus_2: J11.3, J12.2, J13.2, J14.3, U3.14 (I5), U4.14 (I5), U5.14 (I5), U6.14 (I5)
bus_3: J11.4, J12.1, J13.1, J14.4, U3.15 (I4), U4.15 (I4), U5.15 (I4), U6.15 (I4)
bus_4: J7.1, J8.2, U3.1 (I3), U4.1 (I3), U5.1 (I3), U6.1 (I3), U7.4, U9.4
bus_5: J7.2, J8.1, U3.2 (I2), U4.2 (I2), U5.2 (I2), U6.2 (I2), U8.4, U10.4
ce: J16.2, U10.1
cin: J10.4, U9.1; also elsewhere on the board
cout_n: J9.2, U7.1
cout_s: J10.3, U8.1; also elsewhere on the board
pre_0: J15.4, U3.5 (Z); also elsewhere on the board
pre_1: J15.3, U5.5 (Z); also elsewhere on the board
pre_2: J15.2, U4.5 (Z); also elsewhere on the board
pre_3: J15.1, U6.5 (Z); also elsewhere on the board
presel_0_0: R14.1, U1.15 (QA), U3.11 (S0)
presel_0_1: R12.1, U1.1 (QB), U3.10 (S1)
presel_0_2: R10.1, U1.2 (QC), U3.9 (S2)
presel_1_0: R6.1, U1.4 (QE), U5.11 (S0); also elsewhere on the board
presel_1_1: R4.1, U1.5 (QF), U5.10 (S1)
presel_1_2: R2.1, U1.6 (QG), U5.9 (S2)
presel_2_0: R15.1, U2.15 (QA), U4.11 (S0)
presel_2_1: R13.1, U2.1 (QB), U4.10 (S1)
presel_2_2: R11.1, U2.2 (QC), U4.9 (S2)
presel_3_0: R7.1, U2.4 (QE), U6.11 (S0)
presel_3_1: R5.1, U2.5 (QF), U6.10 (S1)
presel_3_2: R3.1, U2.6 (QG), U6.9 (S2)
xp_ce: R16.1, U2.7 (QH), U10.6
xp_cin: R8.1, U1.3 (QD), U9.6
xp_cout_n: R1.1, U1.7 (QH), U7.6
xp_cout_s: R9.1, U2.3 (QD), U8.6

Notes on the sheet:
SPI through path
power in/out

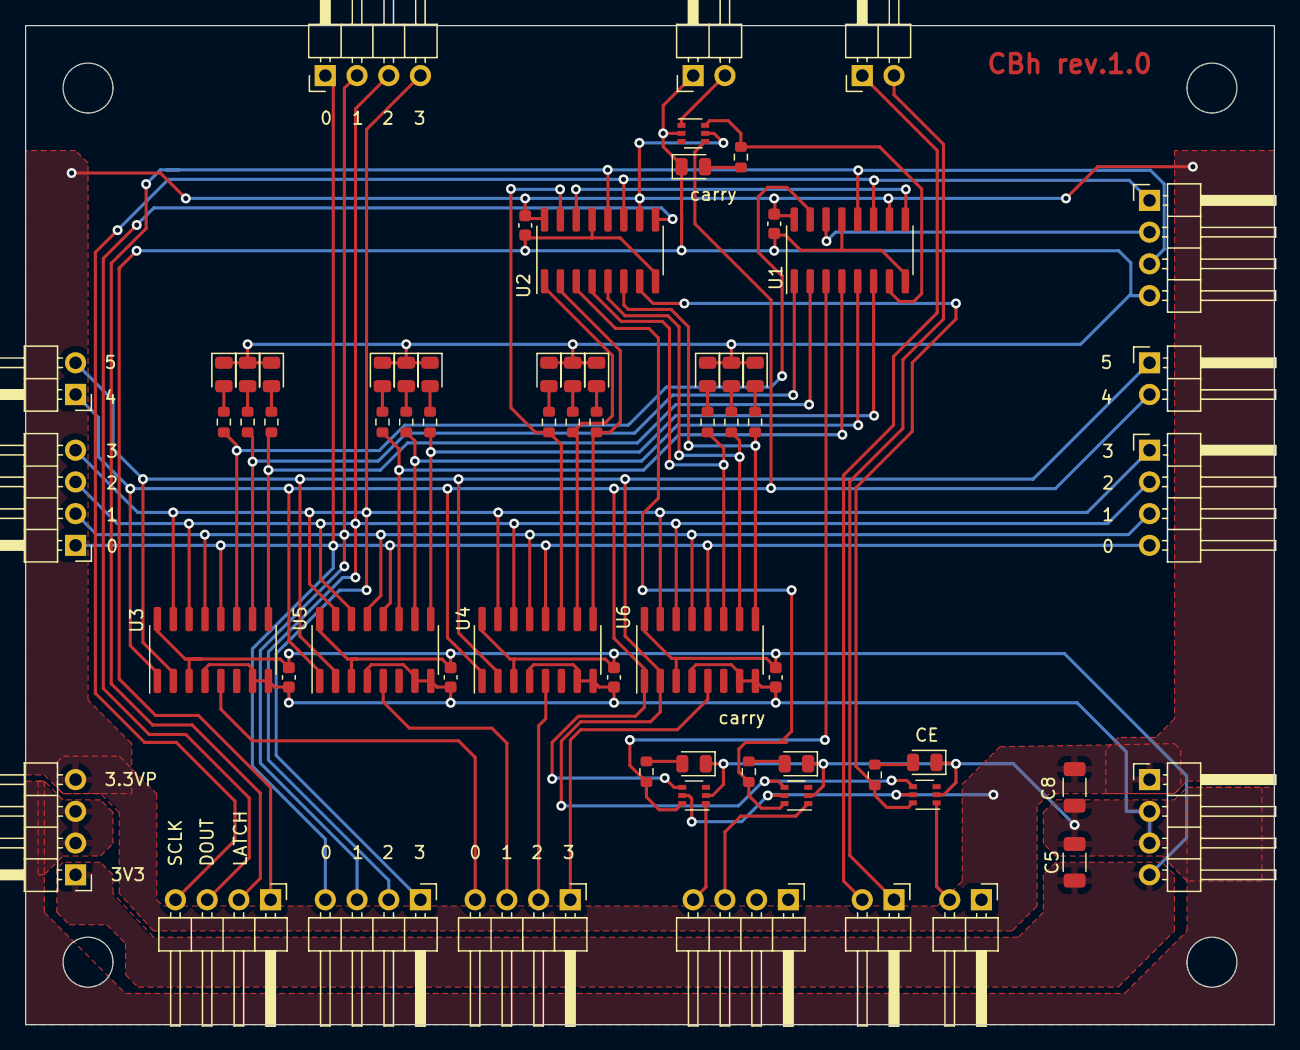
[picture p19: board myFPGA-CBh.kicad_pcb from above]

Board: 2 copper layers, 100.0 x 80.0 mm, 66 parts (0 on the bottom side), 55 nets.

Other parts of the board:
Re: 330R; R_0603_1608Metric
locked: Conn_01x04; PinHeader_1x04_P2.54mm_Horizontal
locked#2: Conn_01x02; PinHeader_1x02_P2.54mm_Horizontal
locked#3, locked#4: Conn_01x04; PinHeader_1x04_P2.54mm_Horizontal

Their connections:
GND: locked.1, locked.2, locked#2.1, locked#4.1; also elsewhere on the board
LATCH: locked#4.2; also elsewhere on the board
MISO: locked#4.3; also elsewhere on the board
unnamed 11: Re.2; also elsewhere on the board
SCLK: locked#4.4; also elsewhere on the board
aresetn: locked#2.2; also elsewhere on the board
cin: locked.4; also elsewhere on the board
cout_s: locked.3; also elsewhere on the board
pre_0: locked#3.4; also elsewhere on the board
pre_1: locked#3.3; also elsewhere on the board
pre_2: locked#3.2; also elsewhere on the board
pre_3: locked#3.1; also elsewhere on the board
presel_1_0: Re.1; also elsewhere on the board

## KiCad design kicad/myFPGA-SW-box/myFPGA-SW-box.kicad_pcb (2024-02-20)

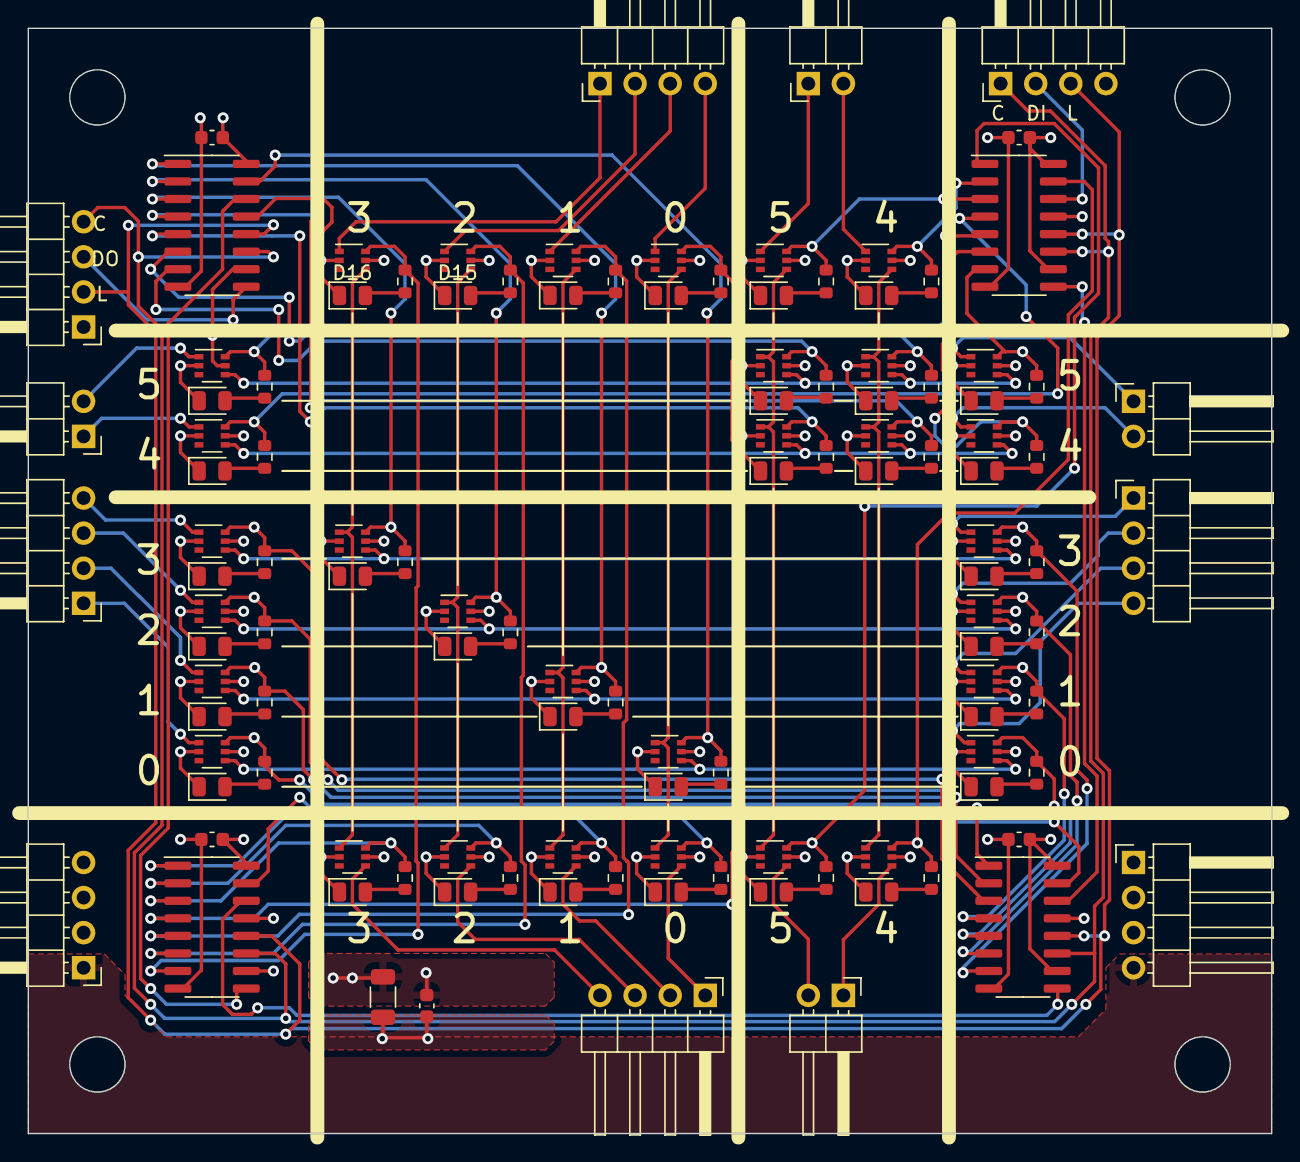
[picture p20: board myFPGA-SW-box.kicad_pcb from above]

Board: 4 copper layers, 90.0 x 80.0 mm, 118 parts (0 on the bottom side), 110 nets.

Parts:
C1, C2, C3, C4, C5: 100n; C_0603_1608Metric
C6: 22u; R_1206_3216Metric
D1, D2, D3, D4, D5, D6, D7, D8, D9, D10, D11, D12, D13, D14, D15, D16, D17, D18, D19, D20, D21, D22, D23, D24, D25, D26, D27, D28, D29, D30, D31, D32: LED (green); LED_0805_2012Metric
J1, J2, J3, J4, J5, J6, J7, J9: Conn_01x04; PinHeader_1x04_P2.54mm_Horizontal
J8, J10, J11, J12: Conn_01x02; PinHeader_1x02_P2.54mm_Horizontal
R1, R2, R3, R4, R5, R6, R7, R8, R9, R10, R11, R12, R13, R14, R15, R16, R18, R19, R20, R21, R22, R23, R24, R25, R26, R27, R28, R29, R30, R31, R32: 10k; R_0603_1608Metric
Re: 10k; R_0603_1608Metric
U1, U2, U3, U4: 74HC595; SOIC-16_3.9x9.9mm_P1.27mm
U5, U6, U7, U8, U9, U10, U11, U12, U13, U14, U15, U16, U17, U18, U19, U20, U21, U22, U23, U24, U25, U26, U27, U28, U29, U30, U31, U32, U33, U34, U35, U36: NC7SB3157P6X; SOT-363_SC-70-6

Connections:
+3.3VP: C1.1, C2.1, C3.1, C4.1, C5.1, C6.1, J7.4, J9.1, U1.10 (~SRCLR), U1.16 (VCC), U2.10 (~SRCLR), U2.16 (VCC), U3.10 (~SRCLR), U3.16 (VCC), U4.10 (~SRCLR), U4.16 (VCC), U5.5 (V+), U6.5 (V+), U7.5 (V+), U8.5 (V+), U9.5 (V+), U10.5 (V+), U11.5 (V+), U12.5 (V+), U13.5 (V+), U14.5 (V+), U15.5 (V+), U16.5 (V+), U17.5 (V+), U18.5 (V+), U19.5 (V+), U20.5 (V+), U21.5 (V+), U22.5 (V+), U23.5 (V+), U24.5 (V+), U25.5 (V+), U26.5 (V+), U27.5 (V+), U28.5 (V+), U29.5 (V+), U30.5 (V+), U31.5 (V+), U32.5 (V+), U33.5 (V+), U34.5 (V+), U35.5 (V+), U36.5 (V+)
+3V3: J7.1, J9.4
/east_0: J6.4, U24.1
/east_1: J6.3, U23.1
/east_2: J6.2, U22.1
/east_3: J6.1, U21.1
/north_0: J5.4, U19.1
/north_1: J5.3, U16.1
/north_2: J5.2, U13.1
/north_3: J5.1, U10.1
/prio_east_0: J12.2, U36.1
/prio_east_1: J12.1, U35.1
/prio_north_0: J10.2, U31.1
/prio_north_1: J10.1, U27.1
/prio_south_0: J11.1, U34.4
/prio_south_1: J11.2, U30.4
/prio_west_0: J8.1, U26.1
/prio_west_1: J8.2, U25.1
/south_0: J4.1, U20.4
/south_1: J4.2, U17.4
/south_2: J4.3, U14.4
/south_3: J4.4, U11.4
/west_0: J3.1, U8.1
/west_1: J3.2, U7.1
/west_2: J3.3, U6.1
/west_3: J3.4, U5.1
GND: C1.2, C2.2, C3.2, C4.2, C5.2, C6.2, D1.1 (K), D2.1 (K), D3.1 (K), D4.1 (K), D5.1 (K), D6.1 (K), D7.1 (K), D8.1 (K), D9.1 (K), D10.1 (K), D11.1 (K), D12.1 (K), D13.1 (K), D14.1 (K), D15.1 (K), D16.1 (K), D17.1 (K), D18.1 (K), D19.1 (K), D20.1 (K), D21.1 (K), D22.1 (K), D23.1 (K), D24.1 (K), D25.1 (K), D26.1 (K), D27.1 (K), D28.1 (K), D29.1 (K), D30.1 (K), D31.1 (K), D32.1 (K), J1.4, J2.1, J7.2, J7.3, J9.2, J9.3, U1.8 (GND), U1.13 (~OE), U2.8 (GND), U2.13 (~OE), U3.8 (GND), U3.13 (~OE), U4.8 (GND), U4.13 (~OE), U5.2 (GND), U6.2 (GND), U7.2 (GND), U8.2 (GND), U9.2 (GND), U10.2 (GND), U11.2 (GND), U12.2 (GND), U13.2 (GND), U14.2 (GND), U15.2 (GND), U16.2 (GND), U17.2 (GND), U18.2 (GND), U19.2 (GND), U20.2 (GND), U21.2 (GND), U22.2 (GND), U23.2 (GND), U24.2 (GND), U25.2 (GND), U26.2 (GND), U27.2 (GND), U28.2 (GND), U29.2 (GND), U30.2 (GND), U31.2 (GND), U32.2 (GND), U33.2 (GND), U34.2 (GND), U35.2 (GND), U36.2 (GND)
LATCH: J1.3, J2.2, U1.12 (RCLK), U2.12 (RCLK), U3.12 (RCLK), U4.12 (RCLK)
MISO: J2.3, U4.9 (QH')
MOSI: J1.2, U1.14 (SER)
unnamed: D1.2 (A), R1.2
unnamed: D2.2 (A), R2.2
unnamed: D3.2 (A), R3.2
unnamed: D4.2 (A), R4.2
unnamed: D5.2 (A), R5.2
unnamed: D6.2 (A), R6.2
unnamed: D7.2 (A), R7.2
unnamed: D8.2 (A), R8.2
unnamed: D9.2 (A), R9.2
unnamed: D10.2 (A), R10.2
unnamed: D11.2 (A), R11.2
unnamed: D12.2 (A), R12.2
unnamed: D13.2 (A), R13.2
unnamed: D14.2 (A), R14.2
unnamed: D15.2 (A), R15.2
unnamed: D16.2 (A), R16.2
unnamed: D17.2 (A), Re.2
unnamed: D18.2 (A), R18.2
unnamed: D19.2 (A), R19.2
unnamed: D20.2 (A), R20.2
unnamed: D21.2 (A), R21.2
unnamed: D22.2 (A), R22.2
unnamed: D23.2 (A), R23.2
unnamed: D24.2 (A), R24.2
unnamed: D25.2 (A), R25.2
unnamed: D26.2 (A), R26.2
unnamed: D27.2 (A), R27.2
unnamed: D28.2 (A), R28.2
unnamed: D29.2 (A), R29.2
unnamed: D30.2 (A), R30.2
unnamed: D31.2 (A), R31.2
unnamed: D32.2 (A), R32.2
unnamed: U1.9 (QH'), U2.14 (SER)
unnamed: U2.9 (QH'), U3.14 (SER)
unnamed: U3.9 (QH'), U4.14 (SER)
unnamed: U9.1, U10.4, U11.1
unnamed: U12.1, U13.4, U14.1
unnamed: U6.4, U12.4, U22.4
unnamed: U15.1, U16.4, U17.1
unnamed: U7.4, U15.4, U23.4
unnamed: U18.1, U19.4, U20.1
unnamed: U8.4, U18.4, U24.4
unnamed: U5.4, U9.4, U21.4
unnamed: U25.4, U28.4, U32.4, U35.4
unnamed: U26.4, U29.4, U33.4, U36.4
unnamed: U27.4, U28.1, U29.1, U30.1
unnamed: U31.4, U32.1, U33.1, U34.1
SCLK: J1.1, J2.4, U1.11 (SRCLK), U2.11 (SRCLK), U3.11 (SRCLK), U4.11 (SRCLK)
sw_8: R9.1, U3.15 (QA), U20.6
sw_9: R10.1, U3.1 (QB), U17.6
sw_10: R11.1, U3.2 (QC), U14.6
sw_11: R12.1, U3.3 (QD), U11.6
sw_12: R13.1, U3.4 (QE), U19.6
sw_13: R14.1, U3.5 (QF), U16.6
sw_14: R15.1, U3.6 (QG), U13.6
sw_15: R16.1, U3.7 (QH), U10.6
sw_16: R25.1, U2.15 (QA), U8.6
sw_17: R26.1, U2.1 (QB), U7.6
sw_18: R27.1, U2.2 (QC), U6.6
sw_19: R28.1, U2.3 (QD), U5.6
sw_20: R29.1, U2.4 (QE), U24.6
sw_21: R30.1, U2.5 (QF), U23.6
sw_22: R31.1, U2.6 (QG), U22.6
sw_23: R32.1, U2.7 (QH), U21.6
sw_24: Re.1, U1.15 (QA), U34.6
sw_25: R18.1, U1.1 (QB), U30.6
sw_26: R19.1, U1.2 (QC), U31.6
sw_27: R20.1, U1.3 (QD), U27.6
sw_28: R21.1, U1.4 (QE), U26.6
sw_29: R22.1, U1.5 (QF), U25.6
sw_30: R23.1, U1.6 (QG), U36.6
sw_31: R24.1, U1.7 (QH), U35.6
xp_0: R1.1, U4.15 (QA), U18.6
xp_1: R2.1, U4.1 (QB), U15.6
xp_2: R3.1, U4.2 (QC), U12.6
xp_3: R4.1, U4.3 (QD), U9.6
xp_4: R5.1, U4.4 (QE), U33.6
xp_5: R6.1, U4.5 (QF), U29.6
xp_6: R7.1, U4.6 (QG), U32.6
xp_7: R8.1, U4.7 (QH), U28.6

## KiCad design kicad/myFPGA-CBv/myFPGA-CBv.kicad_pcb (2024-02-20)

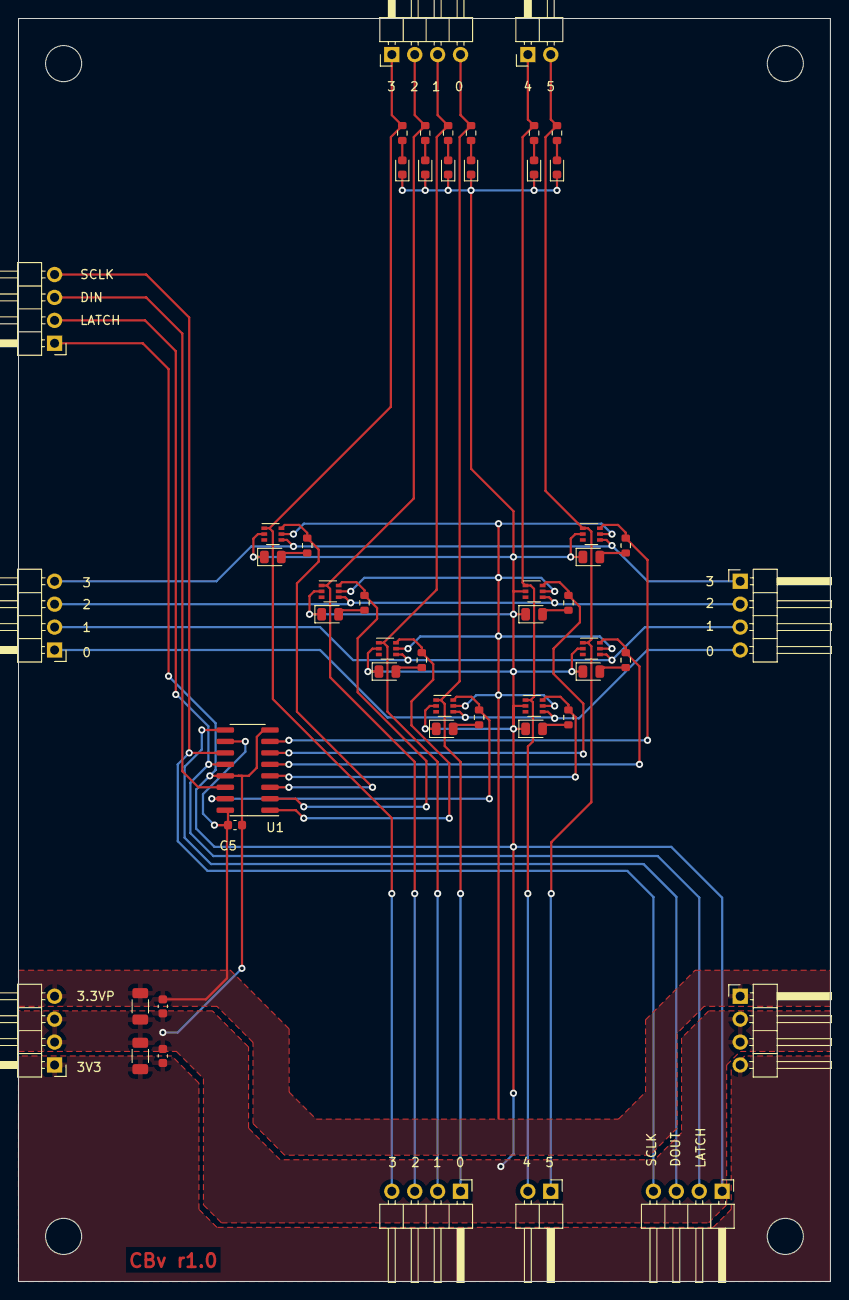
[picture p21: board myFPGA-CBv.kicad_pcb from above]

Board: 2 copper layers, 90.0 x 140.0 mm, 52 parts (0 on the bottom side), 39 nets.

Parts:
C1, C3, C5: 100n; C_0603_1608Metric
C2, C4: 22u; R_1206_3216Metric
D1, D2, D3, D4, D5, D6, D7, D8: LED (green); LED_0805_2012Metric
D9, D10, D11, D12, D13, D14: LED (blue); LED_0603_1608Metric
J1, J2, J3, J4, J7, J8, J9, J10: Conn_01x04; PinHeader_1x04_P2.54mm_Horizontal
J5, J6: Conn_01x02; PinHeader_1x02_P2.54mm_Horizontal
R1, R2, R3, R4, R5, R6, R7, R8, R9, R10, R11, R12, R13, R14: 10k; R_0603_1608Metric
U1: 74HC595; SOIC-16_3.9x9.9mm_P1.27mm
U2, U3, U4, U5, U6, U7, U8, U9: NC7SB3157P6X; SOT-363_SC-70-6

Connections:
+3.3VP: C1.1, C2.1, C5.1, J1.4, J7.1, U1.10 (~SRCLR), U1.16 (VCC), U2.5 (V+), U3.5 (V+), U4.5 (V+), U5.5 (V+), U6.5 (V+), U7.5 (V+), U8.5 (V+), U9.5 (V+)
+3V3: C3.1, C4.1, J1.1, J7.4
/s_0: J2.1, J8.4, U5.4, U8.4
/s_1: J2.2, J8.3, U4.4, U7.4
/s_2: J2.3, J8.2, U3.4, U6.4
/s_3: J2.4, J8.1, U2.4, U9.4
GND: C1.2, C2.2, C3.2, C4.2, C5.2, D1.1 (K), D2.1 (K), D3.1 (K), D4.1 (K), D5.1 (K), D6.1 (K), D7.1 (K), D8.1 (K), D9.1 (K), D10.1 (K), D11.1 (K), D12.1 (K), D13.1 (K), D14.1 (K), J1.2, J1.3, J7.2, J7.3, J9.1, J10.1, U1.8 (GND), U1.13 (~OE), U2.2 (GND), U3.2 (GND), U4.2 (GND), U5.2 (GND), U6.2 (GND), U7.2 (GND), U8.2 (GND), U9.2 (GND)
LATCH: J9.2, J10.2, U1.12 (RCLK)
MISO: J10.3, U1.9 (QH')
MOSI: J9.3, U1.14 (SER)
unnamed: D1.2 (A), R1.2
unnamed: D2.2 (A), R2.2
unnamed: D3.2 (A), R3.2
unnamed: D4.2 (A), R4.2
unnamed: D5.2 (A), R5.2
unnamed: D6.2 (A), R6.2
unnamed: D7.2 (A), R7.2
unnamed: D8.2 (A), R8.2
unnamed: D9.2 (A), R9.2
unnamed: D10.2 (A), R10.2
unnamed: D11.2 (A), R11.2
unnamed: D12.2 (A), R12.2
unnamed: D13.2 (A), R13.2
unnamed: D14.2 (A), R14.2
SCLK: J9.4, J10.4, U1.11 (SRCLK)
bus_0: J3.1, J4.4, R9.1, U5.1
bus_1: J3.2, J4.3, R10.1, U4.1
bus_2: J3.3, J4.2, R11.1, U3.1
bus_3: J3.4, J4.1, R12.1, U2.1
prio_0: J5.2, J6.1, R13.1, U7.1, U9.1
prio_1: J5.1, J6.2, R14.1, U6.1, U8.1
xp_0: R1.1, U1.15 (QA), U5.6
xp_1: R2.1, U1.1 (QB), U4.6
xp_2: R3.1, U1.2 (QC), U3.6
xp_3: R4.1, U1.3 (QD), U2.6
xp_4: R5.1, U1.4 (QE), U8.6
xp_5: R6.1, U1.5 (QF), U7.6
xp_6: R7.1, U1.6 (QG), U6.6
xp_7: R8.1, U1.7 (QH), U9.6

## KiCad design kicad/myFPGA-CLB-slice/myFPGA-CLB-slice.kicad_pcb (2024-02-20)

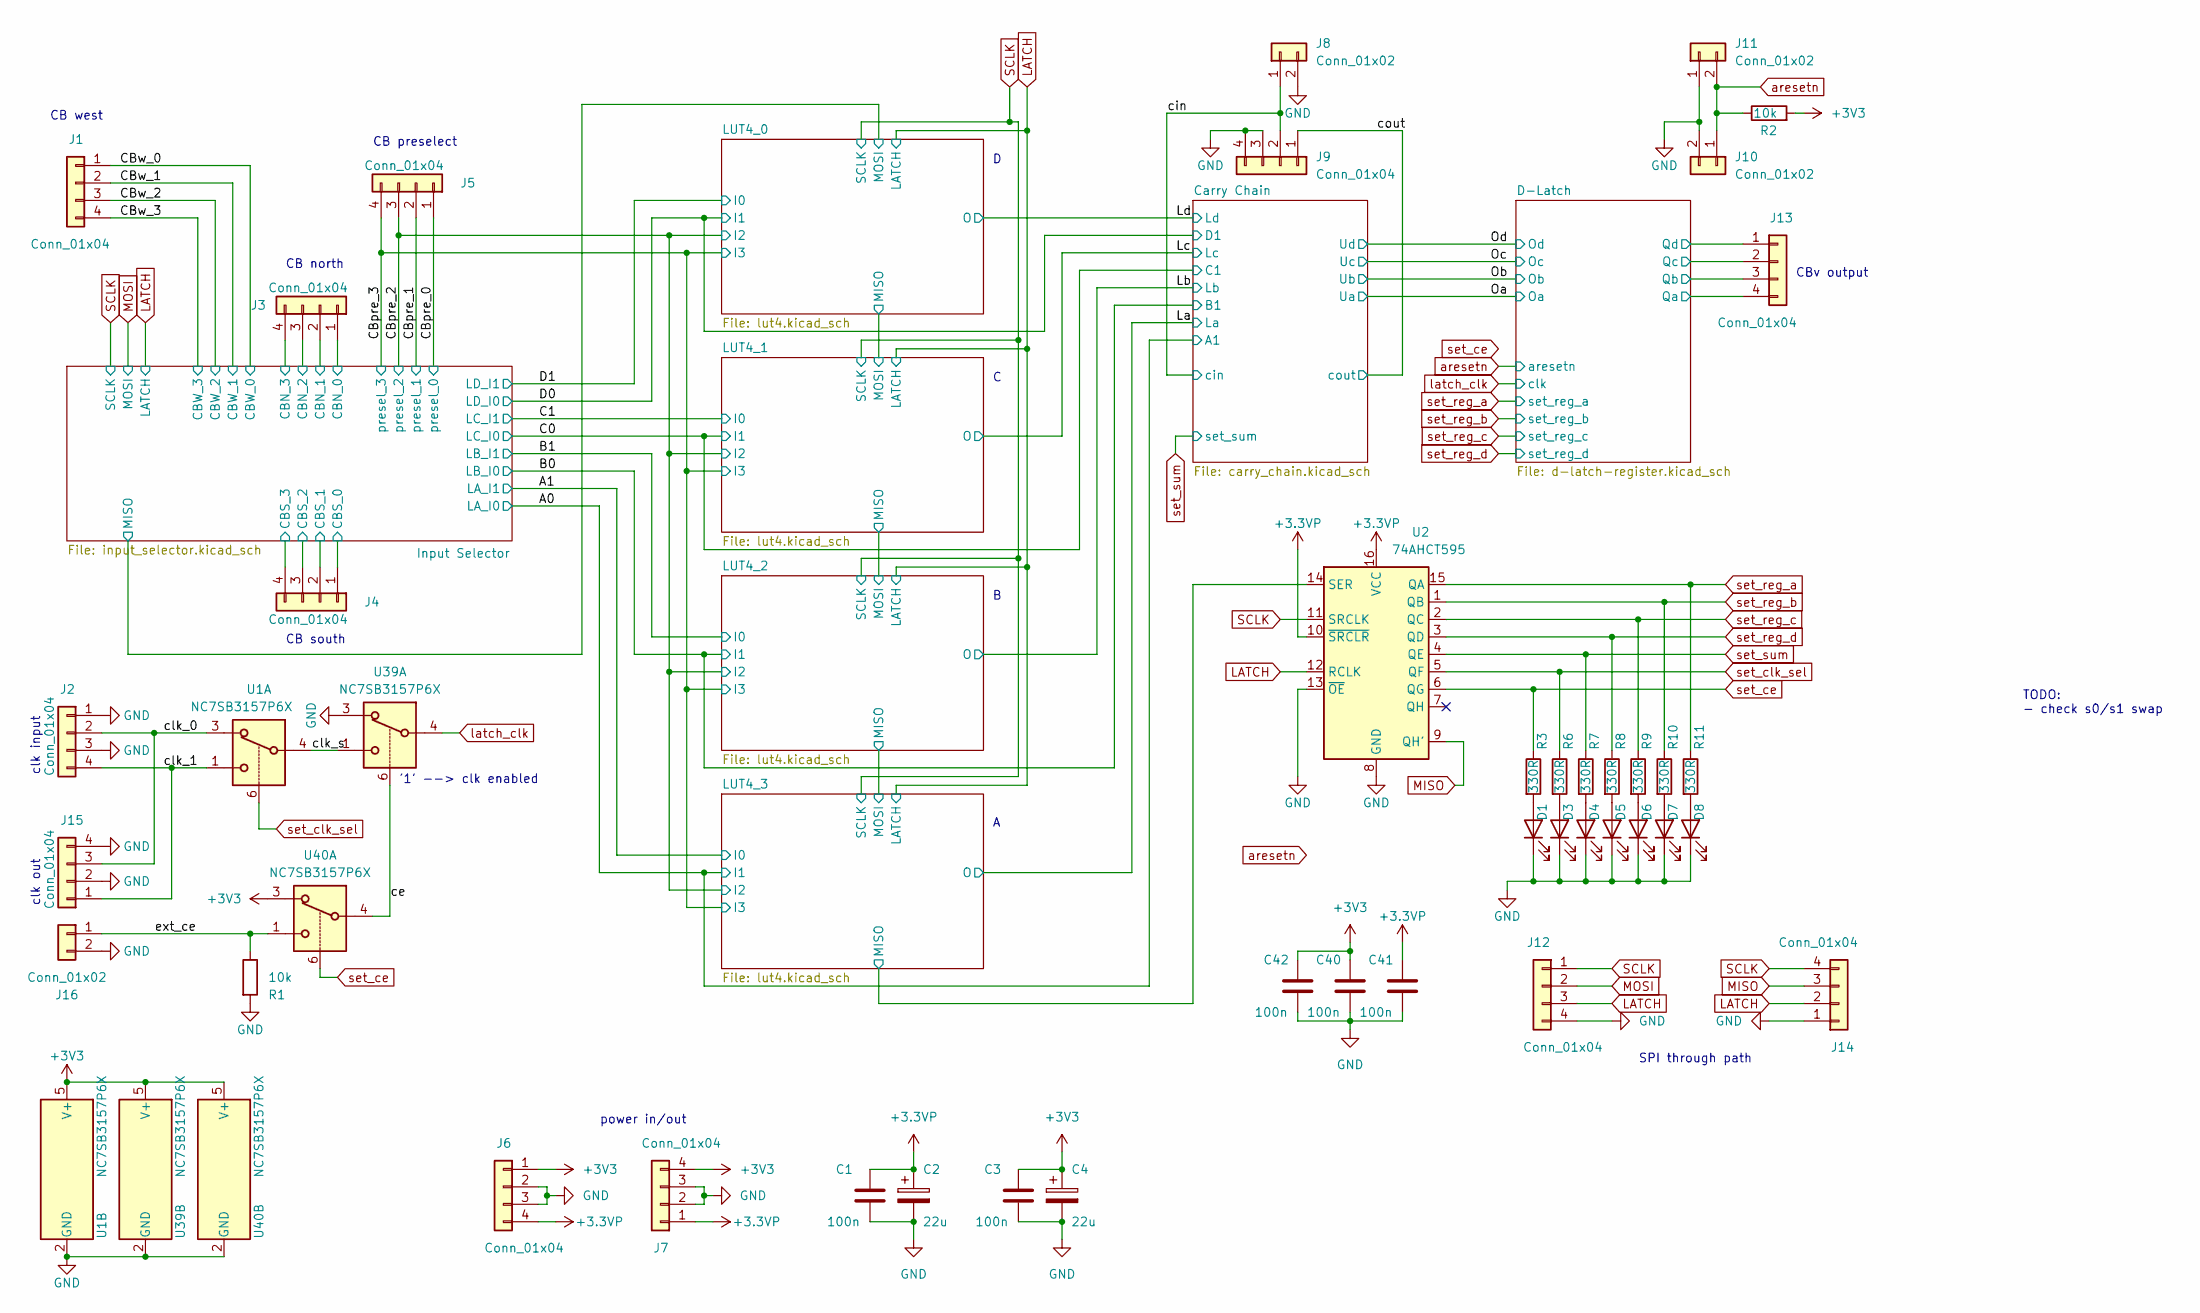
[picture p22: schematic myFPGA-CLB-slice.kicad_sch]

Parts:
C1, C3, C40, C41, C42: 100n; C_0603_1608Metric; Voltage 50; Part Nr. CC0603KRX7R9BB104; JLCPCB Part # C14663
C2, C4: 22u; R_1206_3216Metric; Voltage 25; Part Nr. CL31A226KAHNNNE; JLCPCB Part # C12891
D1, D3, D4, D5, D6, D7, D8: LED (green); LED_0805_2012Metric; Part Nr. C2297; JLCPCB Part # C2297
J1, J2, J3, J4, J5, J6, J7, J9, J12, J13, J14, J15: Conn_01x04; PinHeader_1x04_P2.54mm_Horizontal; Part Nr. do not place; JLCPCB Part # do not place
J8, J10, J11, J16: Conn_01x02; PinHeader_1x02_P2.54mm_Horizontal; Part Nr. do not place; JLCPCB Part # do not place
R1, R2: 10k; R_0603_1608Metric; Part Nr. 0603WAF1002T5E; JLCPCB Part # C25804
R3, R6, R7, R8, R9, R10, R11: 330R; R_0603_1608Metric; Part Nr. 0603WAF3300T5E; JLCPCB Part # C23138
U1, U39, U40: NC7SB3157P6X; SOT-363_SC-70-6; Part Nr. 74LVC1G157GW; JLCPCB Part # C135822
U2: 74AHCT595; SOIC-16_3.9x9.9mm_P1.27mm; Part Nr. 74HC595D; JLCPCB Part # C5947

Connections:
+3.3VP: C1.1, C2.1, C41.1, J6.4, J7.1, U2.10 (~SRCLR), U2.16 (VCC); also elsewhere on the board
+3V3: C3.1, C4.1, C40.1, C42.1, J6.1, J7.4, R2.2, U1.5 (V+), U39.5 (V+), U40.3, U40.5 (V+); also elsewhere on the board
/CBpre_0: J5.1; also elsewhere on the board
/CBpre_1: J5.2; also elsewhere on the board
/CBpre_2: J5.3; also elsewhere on the board
/CBpre_3: J5.4; also elsewhere on the board
/CBw_0: J1.1; also elsewhere on the board
/CBw_1: J1.2; also elsewhere on the board
/CBw_2: J1.3; also elsewhere on the board
/CBw_3: J1.4; also elsewhere on the board
/D-Latch/Qa: J13.4; also elsewhere on the board
/D-Latch/Qb: J13.3; also elsewhere on the board
/D-Latch/Qc: J13.2; also elsewhere on the board
/D-Latch/Qd: J13.1; also elsewhere on the board
/Input Selector/CBN_0: J3.1; also elsewhere on the board
/Input Selector/CBN_1: J3.2; also elsewhere on the board
/Input Selector/CBN_2: J3.3; also elsewhere on the board
/Input Selector/CBN_3: J3.4; also elsewhere on the board
/Input Selector/CBS_0: J4.1; also elsewhere on the board
/Input Selector/CBS_1: J4.2; also elsewhere on the board
/Input Selector/CBS_2: J4.3; also elsewhere on the board
/Input Selector/CBS_3: J4.4; also elsewhere on the board
/LUT4_3/MISO: U2.14 (SER); also elsewhere on the board
/ce: U39.6, U40.4
/cin: J8.1, J9.2; also elsewhere on the board
/clk_0: J2.2, J15.3, U1.3
/clk_1: J2.4, J15.1, U1.1
/clk_s: U1.4, U39.1
/cout: J9.1; also elsewhere on the board
/ext_ce: J16.1, R1.1, U40.1
GND: C1.2, C2.2, C3.2, C4.2, C40.2, C41.2, C42.2, D1.1 (K), D3.1 (K), D4.1 (K), D5.1 (K), D6.1 (K), D7.1 (K), D8.1 (K), J2.1, J2.3, J6.2, J6.3, J7.2, J7.3, J8.2, J9.3, J9.4, J10.2, J11.1, J12.4, J14.1, J15.2, J15.4, J16.2, R1.2, U1.2 (GND), U2.8 (GND), U2.13 (~OE), U39.2 (GND), U39.3, U40.2 (GND); also elsewhere on the board
LATCH: J12.3, J14.2, U2.12 (RCLK); also elsewhere on the board
MISO: J14.3, U2.9 (QH')
MOSI: J12.2; also elsewhere on the board
unnamed: D1.2 (A), R3.2
unnamed: D3.2 (A), R6.2
unnamed: D4.2 (A), R7.2
unnamed: D5.2 (A), R8.2
unnamed: D6.2 (A), R9.2
unnamed: D7.2 (A), R10.2
unnamed: D8.2 (A), R11.2
SCLK: J12.1, J14.4, U2.11 (SRCLK); also elsewhere on the board
aresetn: J10.1, J11.2, R2.1; also elsewhere on the board
latch_clk: U39.4; also elsewhere on the board
set_ce: R3.1, U2.6 (QG), U40.6
set_clk_sel: R6.1, U1.6, U2.5 (QF)
set_reg_a: R11.1, U2.15 (QA); also elsewhere on the board
set_reg_b: R10.1, U2.1 (QB); also elsewhere on the board
set_reg_c: R9.1, U2.2 (QC); also elsewhere on the board
set_reg_d: R8.1, U2.3 (QD); also elsewhere on the board
set_sum: R7.1, U2.4 (QE); also elsewhere on the board

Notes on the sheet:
clk input
CB south
CB preselect
CB north
clk out
CB west
'1' --> clk enabled
TODO: - check s0/s1 swap
CBv output
SPI through path
power in/out

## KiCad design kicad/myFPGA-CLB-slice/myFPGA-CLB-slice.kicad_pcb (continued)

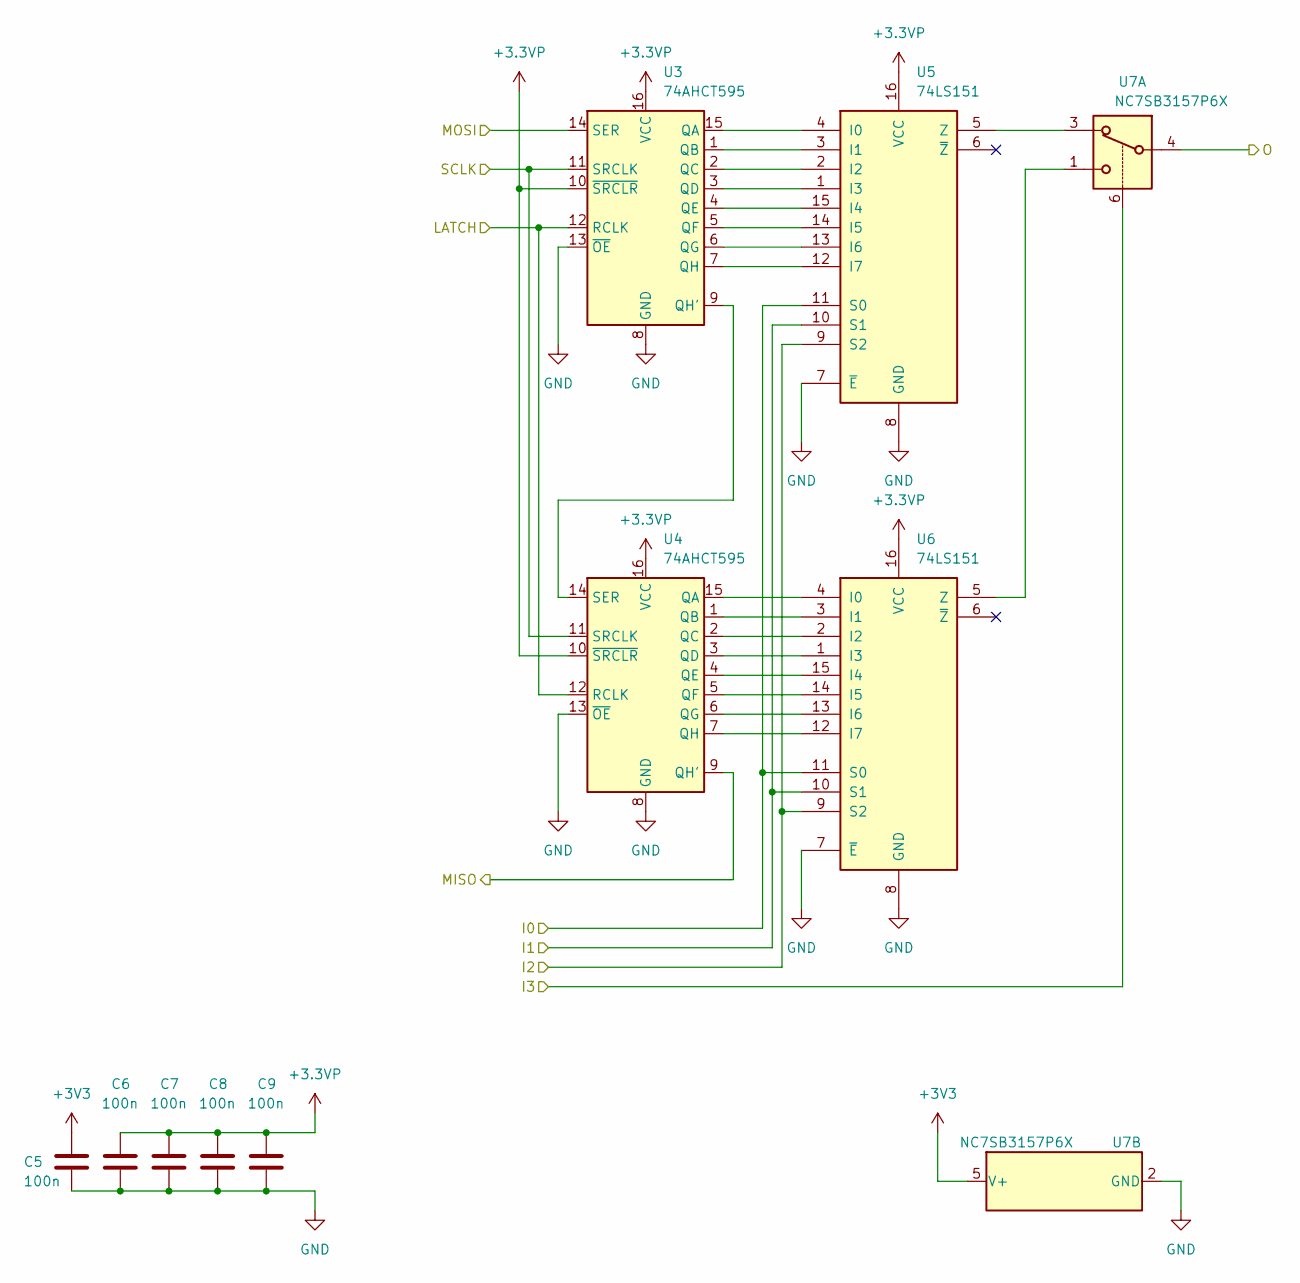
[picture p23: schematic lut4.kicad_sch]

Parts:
C5, C6, C7, C8, C9: 100n; C_0603_1608Metric; Voltage 50; Part Nr. CC0603KRX7R9BB104; JLCPCB Part # C14663
U3, U4: 74AHCT595; SOIC-16_3.9x9.9mm_P1.27mm; Part Nr. 74HC595D; JLCPCB Part # C5947
U5, U6: 74LS151; TSSOP-16_4.4x5mm_P0.65mm; Part Nr. MC74HC151ADTR2G; JLCPCB Part # C152523
U7: NC7SB3157P6X; SOT-363_SC-70-6; Part Nr. 74LVC1G157GW; JLCPCB Part # C135822

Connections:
+3.3VP: C6.1, C7.1, C8.1, C9.1, U3.10 (~SRCLR), U3.16 (VCC), U4.10 (~SRCLR), U4.16 (VCC), U5.16 (VCC), U6.16 (VCC); also elsewhere on the board
+3V3: C5.1, U7.5 (V+); also elsewhere on the board
/CBpre_2: U5.9 (S2), U6.9 (S2); also elsewhere on the board
/CBpre_3: U7.6; also elsewhere on the board
/D0: U5.10 (S1), U6.10 (S1); also elsewhere on the board
/D1: U5.11 (S0), U6.11 (S0); also elsewhere on the board
/Input Selector/MISO: U3.14 (SER); also elsewhere on the board
/LUT4_0/MISO: U4.9 (QH'); also elsewhere on the board
/Ld: U7.4; also elsewhere on the board
GND: C5.2, C6.2, C7.2, C8.2, C9.2, U3.8 (GND), U3.13 (~OE), U4.8 (GND), U4.13 (~OE), U5.7 (~E), U5.8 (GND), U6.7 (~E), U6.8 (GND), U7.2 (GND); also elsewhere on the board
LATCH: U3.12 (RCLK), U4.12 (RCLK); also elsewhere on the board
unnamed: U3.15 (QA), U5.4 (I0)
unnamed: U3.1 (QB), U5.3 (I1)
unnamed: U3.2 (QC), U5.2 (I2)
unnamed: U3.3 (QD), U5.1 (I3)
unnamed: U3.4 (QE), U5.15 (I4)
unnamed: U3.5 (QF), U5.14 (I5)
unnamed: U3.6 (QG), U5.13 (I6)
unnamed: U3.9 (QH'), U4.14 (SER)
unnamed: U3.7 (QH), U5.12 (I7)
unnamed: U4.15 (QA), U6.4 (I0)
unnamed: U4.1 (QB), U6.3 (I1)
unnamed: U4.2 (QC), U6.2 (I2)
unnamed: U4.3 (QD), U6.1 (I3)
unnamed: U4.4 (QE), U6.15 (I4)
unnamed: U4.5 (QF), U6.14 (I5)
unnamed: U4.6 (QG), U6.13 (I6)
unnamed: U4.7 (QH), U6.12 (I7)
unnamed: U5.5 (Z), U7.3
unnamed: U6.5 (Z), U7.1
SCLK: U3.11 (SRCLK), U4.11 (SRCLK); also elsewhere on the board

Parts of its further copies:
C20, C21, C22, C23, C24, C25, C26, C27, C28, C29, C30, C31, C32, C33, C34: 100n; C_0603_1608Metric; Voltage 50; Part Nr. CC0603KRX7R9BB104; JLCPCB Part # C14663
U19, U20, U24, U25, U29, U30: 74AHCT595; SOIC-16_3.9x9.9mm_P1.27mm; Part Nr. 74HC595D; JLCPCB Part # C5947
U21, U22, U26, U27, U31, U32: 74LS151; TSSOP-16_4.4x5mm_P0.65mm; Part Nr. MC74HC151ADTR2G; JLCPCB Part # C152523
U23, U28, U33: NC7SB3157P6X; SOT-363_SC-70-6; Part Nr. 74LVC1G157GW; JLCPCB Part # C135822

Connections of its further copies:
+3.3VP: C21.1, C22.1, C23.1, C24.1, C26.1, C27.1, C28.1, C29.1, C31.1, C32.1, C33.1, C34.1, U19.10 (~SRCLR), U19.16 (VCC), U20.10 (~SRCLR), U20.16 (VCC), U21.16 (VCC), U22.16 (VCC), U24.10 (~SRCLR), U24.16 (VCC), U25.10 (~SRCLR), U25.16 (VCC), U26.16 (VCC), U27.16 (VCC), U29.10 (~SRCLR), U29.16 (VCC), U30.10 (~SRCLR), U30.16 (VCC), U31.16 (VCC), U32.16 (VCC); also elsewhere on the board
+3V3: C20.1, C25.1, C30.1, U23.5 (V+), U28.5 (V+), U33.5 (V+); also elsewhere on the board
/A0: U31.10 (S1), U32.10 (S1); also elsewhere on the board
/A1: U31.11 (S0), U32.11 (S0); also elsewhere on the board
/B0: U26.10 (S1), U27.10 (S1); also elsewhere on the board
/B1: U26.11 (S0), U27.11 (S0); also elsewhere on the board
/C0: U21.10 (S1), U22.10 (S1); also elsewhere on the board
/C1: U21.11 (S0), U22.11 (S0); also elsewhere on the board
/CBpre_2: U21.9 (S2), U22.9 (S2), U26.9 (S2), U27.9 (S2), U31.9 (S2), U32.9 (S2); also elsewhere on the board
/CBpre_3: U23.6, U28.6, U33.6; also elsewhere on the board
/LUT4_0/MISO: U19.14 (SER); also elsewhere on the board
/LUT4_1/MISO: U20.9 (QH'), U24.14 (SER)
/LUT4_2/MISO: U25.9 (QH'), U29.14 (SER)
/LUT4_3/MISO: U30.9 (QH'); also elsewhere on the board
/La: U33.4; also elsewhere on the board
/Lb: U28.4; also elsewhere on the board
/Lc: U23.4; also elsewhere on the board
GND: C20.2, C21.2, C22.2, C23.2, C24.2, C25.2, C26.2, C27.2, C28.2, C29.2, C30.2, C31.2, C32.2, C33.2, C34.2, U19.8 (GND), U19.13 (~OE), U20.8 (GND), U20.13 (~OE), U21.7 (~E), U21.8 (GND), U22.7 (~E), U22.8 (GND), U23.2 (GND), U24.8 (GND), U24.13 (~OE), U25.8 (GND), U25.13 (~OE), U26.7 (~E), U26.8 (GND), U27.7 (~E), U27.8 (GND), U28.2 (GND), U29.8 (GND), U29.13 (~OE), U30.8 (GND), U30.13 (~OE), U31.7 (~E), U31.8 (GND), U32.7 (~E), U32.8 (GND), U33.2 (GND); also elsewhere on the board
LATCH: U19.12 (RCLK), U20.12 (RCLK), U24.12 (RCLK), U25.12 (RCLK), U29.12 (RCLK), U30.12 (RCLK); also elsewhere on the board
unnamed: U19.15 (QA), U21.4 (I0)
unnamed: U19.1 (QB), U21.3 (I1)
unnamed: U19.2 (QC), U21.2 (I2)
unnamed: U19.3 (QD), U21.1 (I3)
unnamed: U19.4 (QE), U21.15 (I4)
unnamed: U19.5 (QF), U21.14 (I5)
unnamed: U19.6 (QG), U21.13 (I6)
unnamed: U19.9 (QH'), U20.14 (SER)
unnamed: U19.7 (QH), U21.12 (I7)
unnamed: U20.15 (QA), U22.4 (I0)
unnamed: U20.1 (QB), U22.3 (I1)
unnamed: U20.2 (QC), U22.2 (I2)
unnamed: U20.3 (QD), U22.1 (I3)
unnamed: U20.4 (QE), U22.15 (I4)
unnamed: U20.5 (QF), U22.14 (I5)
unnamed: U20.6 (QG), U22.13 (I6)
unnamed: U20.7 (QH), U22.12 (I7)
unnamed: U21.5 (Z), U23.3
unnamed: U22.5 (Z), U23.1
unnamed: U24.15 (QA), U26.4 (I0)
unnamed: U24.1 (QB), U26.3 (I1)
unnamed: U24.2 (QC), U26.2 (I2)
unnamed: U24.3 (QD), U26.1 (I3)
unnamed: U24.4 (QE), U26.15 (I4)
unnamed: U24.5 (QF), U26.14 (I5)
unnamed: U24.6 (QG), U26.13 (I6)
unnamed: U24.9 (QH'), U25.14 (SER)
unnamed: U24.7 (QH), U26.12 (I7)
unnamed: U25.15 (QA), U27.4 (I0)
unnamed: U25.1 (QB), U27.3 (I1)
unnamed: U25.2 (QC), U27.2 (I2)
unnamed: U25.3 (QD), U27.1 (I3)
unnamed: U25.4 (QE), U27.15 (I4)
unnamed: U25.5 (QF), U27.14 (I5)
unnamed: U25.6 (QG), U27.13 (I6)
unnamed: U25.7 (QH), U27.12 (I7)
unnamed: U26.5 (Z), U28.3
unnamed: U27.5 (Z), U28.1
unnamed: U29.15 (QA), U31.4 (I0)
unnamed: U29.1 (QB), U31.3 (I1)
unnamed: U29.2 (QC), U31.2 (I2)
unnamed: U29.3 (QD), U31.1 (I3)
unnamed: U29.4 (QE), U31.15 (I4)
unnamed: U29.5 (QF), U31.14 (I5)
unnamed: U29.6 (QG), U31.13 (I6)
unnamed: U29.9 (QH'), U30.14 (SER)
unnamed: U29.7 (QH), U31.12 (I7)
unnamed: U30.15 (QA), U32.4 (I0)
unnamed: U30.1 (QB), U32.3 (I1)
unnamed: U30.2 (QC), U32.2 (I2)
unnamed: U30.3 (QD), U32.1 (I3)
unnamed: U30.4 (QE), U32.15 (I4)
unnamed: U30.5 (QF), U32.14 (I5)
unnamed: U30.6 (QG), U32.13 (I6)
unnamed: U30.7 (QH), U32.12 (I7)
unnamed: U31.5 (Z), U33.3
unnamed: U32.5 (Z), U33.1
SCLK: U19.11 (SRCLK), U20.11 (SRCLK), U24.11 (SRCLK), U25.11 (SRCLK), U29.11 (SRCLK), U30.11 (SRCLK); also elsewhere on the board

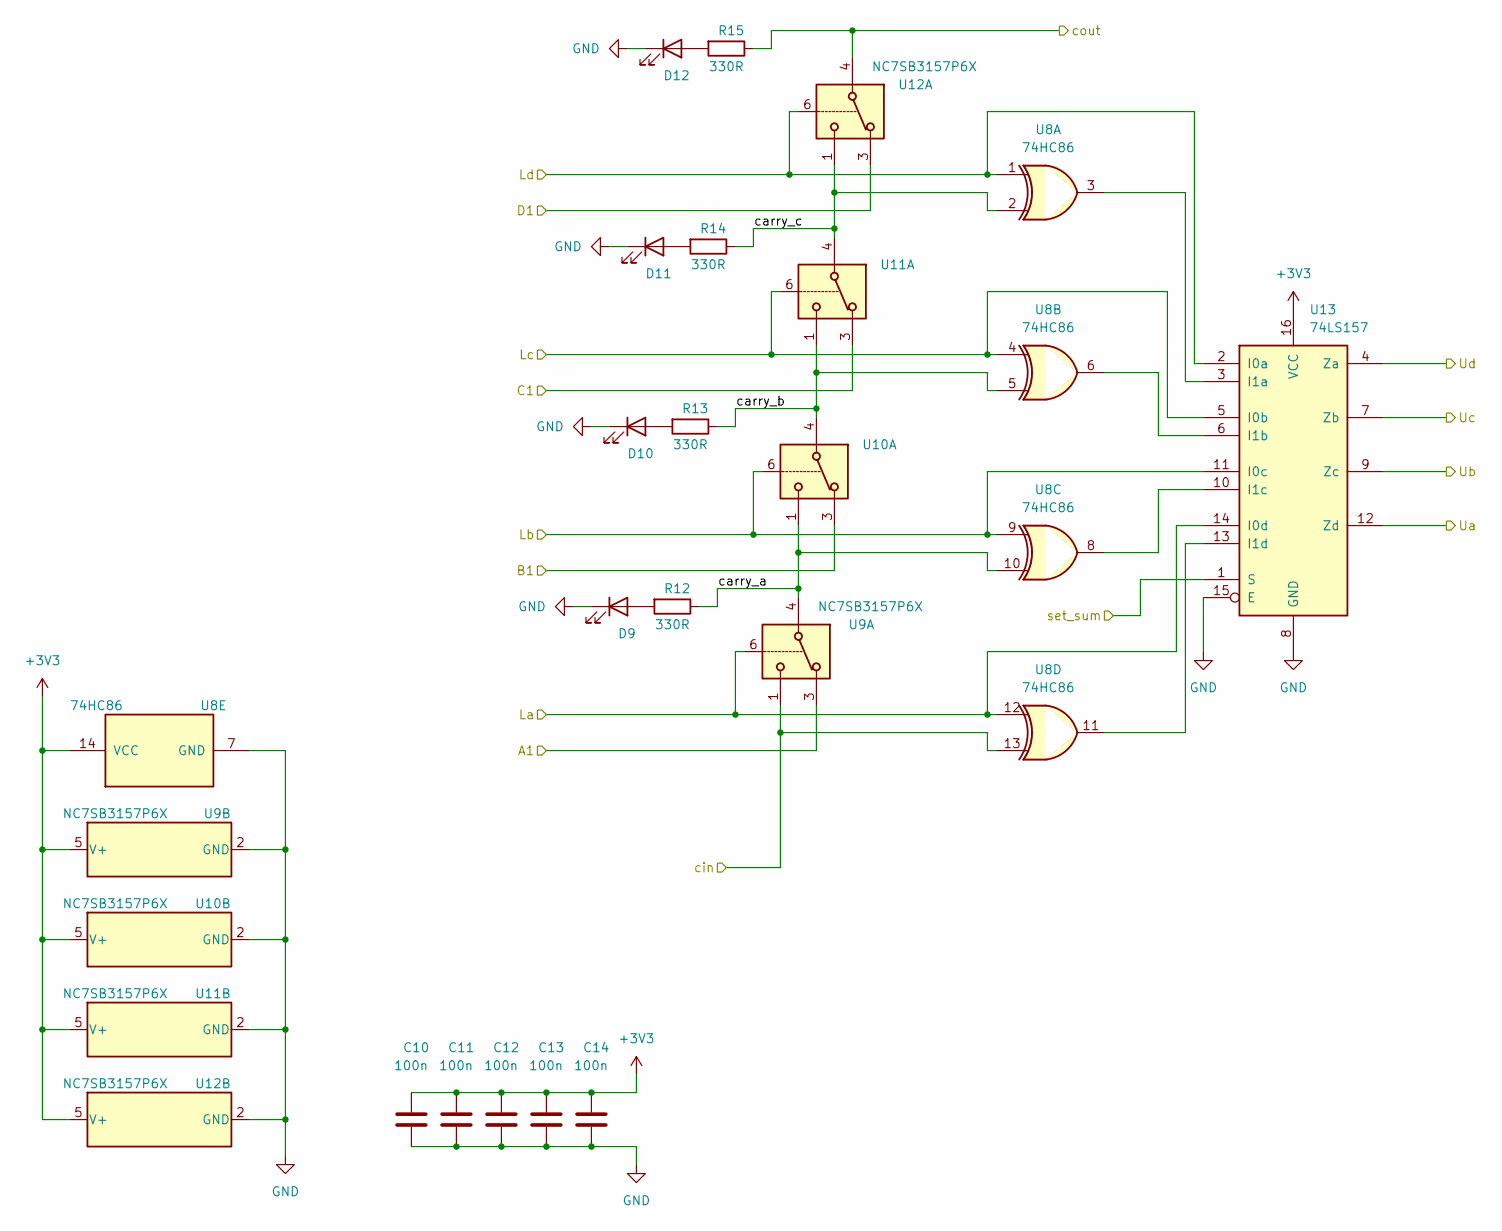
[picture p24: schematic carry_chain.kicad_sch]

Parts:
C10, C11, C12, C13, C14: 100n; C_0603_1608Metric; Voltage 50; Part Nr. CC0603KRX7R9BB104; JLCPCB Part # C14663
D9, D10, D11, D12: LED (blue); LED_0603_1608Metric; Part Nr. 19-217/BHC-ZL1M2RY/3T; JLCPCB Part # C72041
R12, R13, R14, R15: 330R; R_0603_1608Metric; Part Nr. 0603WAF3300T5E; JLCPCB Part # C23138
U8: 74HC86; SOIC-14_3.9x8.7mm_P1.27mm; Part Nr. SN74AHC86DR; JLCPCB Part # C8175
U9, U10, U11, U12: NC7SB3157P6X; SOT-363_SC-70-6; Part Nr. 74LVC1G157GW; JLCPCB Part # C135822
U13: 74LS157; SOIC-16_3.9x9.9mm_P1.27mm; Part Nr. SN74HC157DR; JLCPCB Part # C6823

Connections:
+3V3: C10.1, C11.1, C12.1, C13.1, C14.1, U8.14 (VCC), U9.5 (V+), U10.5 (V+), U11.5 (V+), U12.5 (V+), U13.16 (VCC); also elsewhere on the board
/A0: U9.3; also elsewhere on the board
/B0: U10.3; also elsewhere on the board
/C0: U11.3; also elsewhere on the board
/Carry Chain/carry_a: R12.1, U8.10, U9.4, U10.1
/Carry Chain/carry_b: R13.1, U8.5, U10.4, U11.1
/Carry Chain/carry_c: R14.1, U8.2, U11.4, U12.1
/D0: U12.3; also elsewhere on the board
/La: U8.12, U9.6, U13.14 (I0d); also elsewhere on the board
/Lb: U8.9, U10.6, U13.11 (I0c); also elsewhere on the board
/Lc: U8.4, U11.6, U13.5 (I0b); also elsewhere on the board
/Ld: U8.1, U12.6, U13.2 (I0a); also elsewhere on the board
/Oa: U13.12 (Zd); also elsewhere on the board
/Ob: U13.9 (Zc); also elsewhere on the board
/Oc: U13.7 (Zb); also elsewhere on the board
/Od: U13.4 (Za); also elsewhere on the board
/cin: U8.13, U9.1; also elsewhere on the board
/cout: R15.1, U12.4; also elsewhere on the board
GND: C10.2, C11.2, C12.2, C13.2, C14.2, D9.1 (K), D10.1 (K), D11.1 (K), D12.1 (K), U8.7 (GND), U9.2 (GND), U10.2 (GND), U11.2 (GND), U12.2 (GND), U13.8 (GND), U13.15 (E); also elsewhere on the board
unnamed: D9.2 (A), R12.2
unnamed: D10.2 (A), R13.2
unnamed: D11.2 (A), R14.2
unnamed: D12.2 (A), R15.2
unnamed: U8.3, U13.3 (I1a)
unnamed: U8.6, U13.6 (I1b)
unnamed: U8.8, U13.10 (I1c)
unnamed: U8.11, U13.13 (I1d)
set_sum: U13.1 (S); also elsewhere on the board

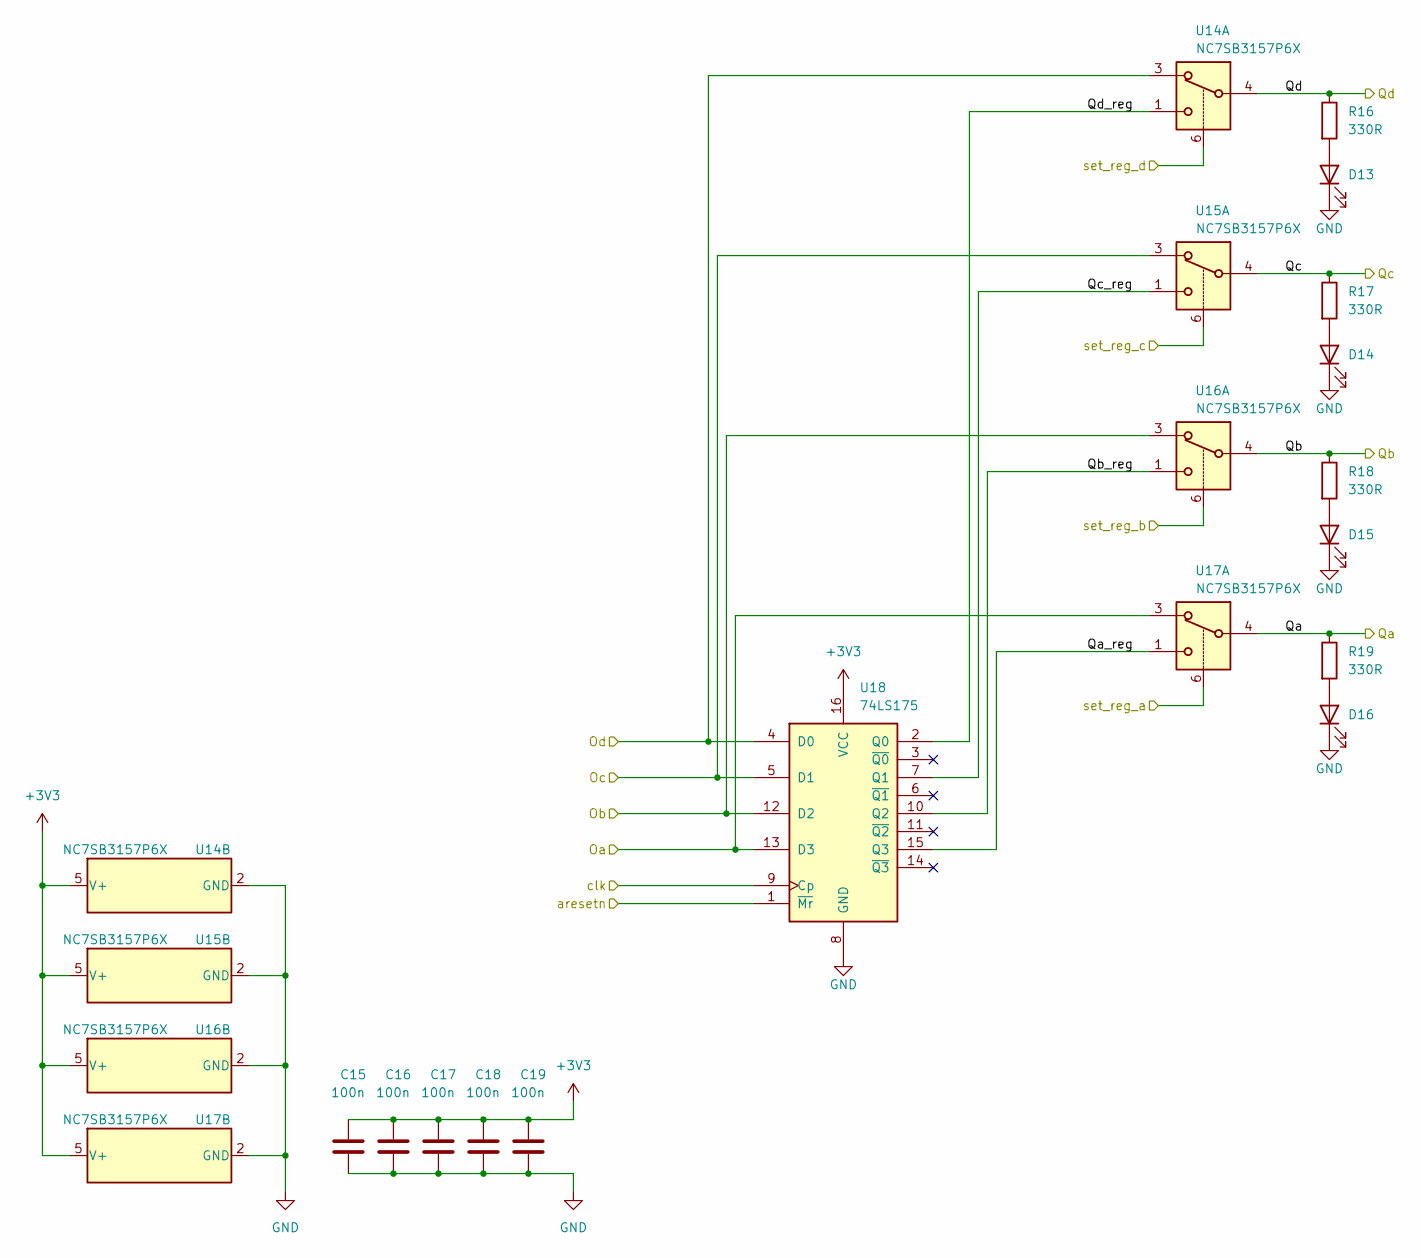
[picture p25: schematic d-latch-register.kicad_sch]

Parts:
C15, C16, C17, C18, C19: 100n; C_0603_1608Metric; Voltage 50; Part Nr. CC0603KRX7R9BB104; JLCPCB Part # C14663
D13, D14, D15, D16: LED (blue); LED_0603_1608Metric; Part Nr. 19-217/BHC-ZL1M2RY/3T; JLCPCB Part # C72041
R16, R17, R18, R19: 330R; R_0603_1608Metric; Part Nr. 0603WAF3300T5E; JLCPCB Part # C23138
U14, U15, U16, U17: NC7SB3157P6X; SOT-363_SC-70-6; Part Nr. 74LVC1G157GW; JLCPCB Part # C135822
U18: 74LS175; SOIC-16_3.9x9.9mm_P1.27mm; Part Nr. CD74AC175M96; JLCPCB Part # C8180

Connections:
+3V3: C15.1, C16.1, C17.1, C18.1, C19.1, U14.5 (V+), U15.5 (V+), U16.5 (V+), U17.5 (V+), U18.16 (VCC); also elsewhere on the board
/D-Latch/Qa: R19.1, U17.4; also elsewhere on the board
/D-Latch/Qa_reg: U17.1, U18.15 (Q3)
/D-Latch/Qb: R18.1, U16.4; also elsewhere on the board
/D-Latch/Qb_reg: U16.1, U18.10 (Q2)
/D-Latch/Qc: R17.1, U15.4; also elsewhere on the board
/D-Latch/Qc_reg: U15.1, U18.7 (Q1)
/D-Latch/Qd: R16.1, U14.4; also elsewhere on the board
/D-Latch/Qd_reg: U14.1, U18.2 (Q0)
/Oa: U17.3, U18.13 (D3); also elsewhere on the board
/Ob: U16.3, U18.12 (D2); also elsewhere on the board
/Oc: U15.3, U18.5 (D1); also elsewhere on the board
/Od: U14.3, U18.4 (D0); also elsewhere on the board
GND: C15.2, C16.2, C17.2, C18.2, C19.2, D13.1 (K), D14.1 (K), D15.1 (K), D16.1 (K), U14.2 (GND), U15.2 (GND), U16.2 (GND), U17.2 (GND), U18.8 (GND); also elsewhere on the board
unnamed: D13.2 (A), R16.2
unnamed: D14.2 (A), R17.2
unnamed: D15.2 (A), R18.2
unnamed: D16.2 (A), R19.2
aresetn: U18.1 (~Mr); also elsewhere on the board
latch_clk: U18.9 (Cp); also elsewhere on the board
set_reg_a: U17.6; also elsewhere on the board
set_reg_b: U16.6; also elsewhere on the board
set_reg_c: U15.6; also elsewhere on the board
set_reg_d: U14.6; also elsewhere on the board

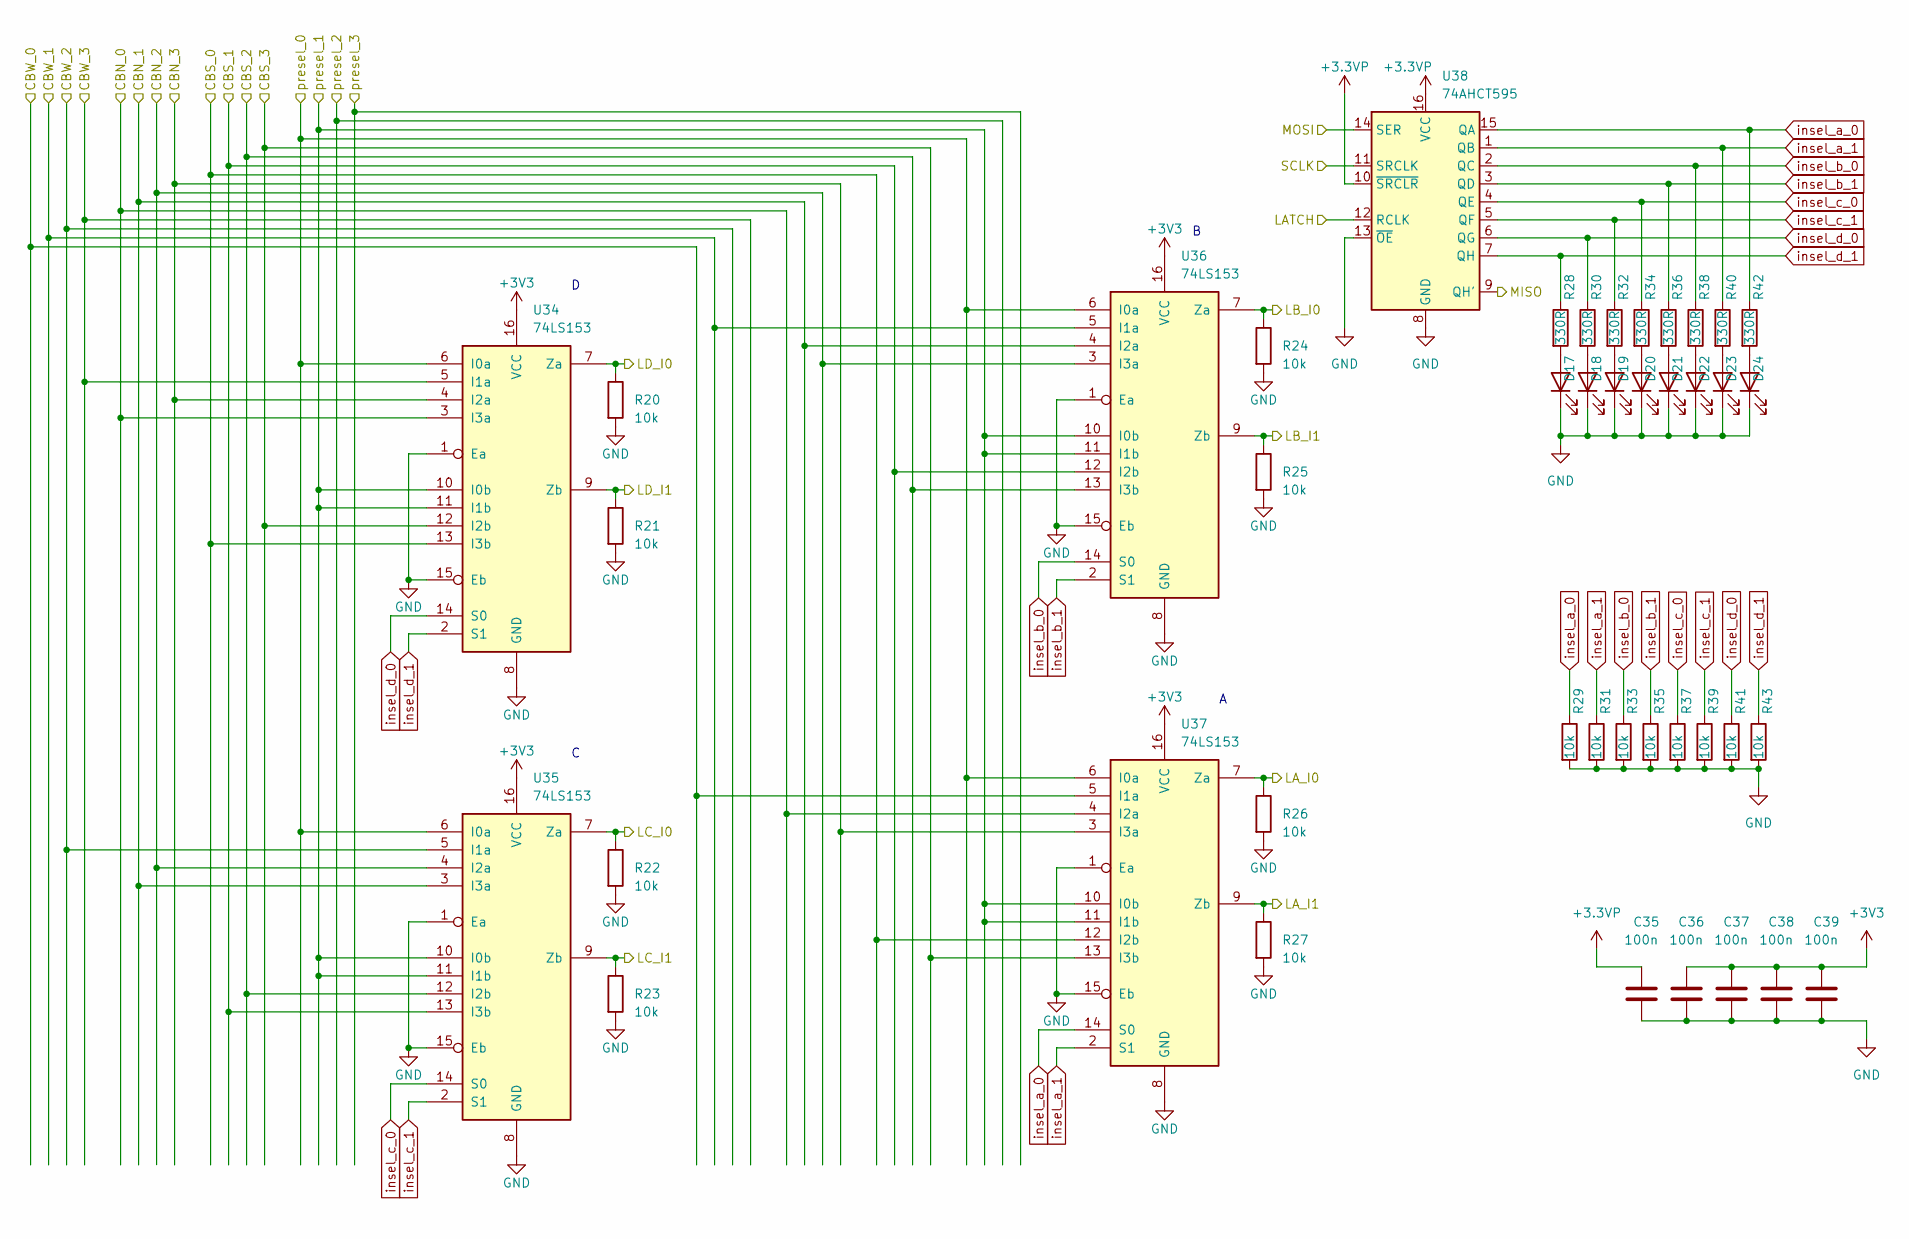
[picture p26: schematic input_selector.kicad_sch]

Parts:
C35, C36, C37, C38, C39: 100n; C_0603_1608Metric; Voltage 50; Part Nr. CC0603KRX7R9BB104; JLCPCB Part # C14663
D17, D18, D19, D20, D21, D22, D23, D24: LED (green); LED_0805_2012Metric; Part Nr. C2297; JLCPCB Part # C2297
R20, R21, R22, R23, R24, R25, R26, R27, R29, R31, R33, R35, R37, R39, R41, R43: 10k; R_0603_1608Metric; Part Nr. 0603WAF1002T5E; JLCPCB Part # C25804
R28, R30, R32, R34, R36, R38, R40, R42: 330R; R_0603_1608Metric; Part Nr. 0603WAF3300T5E; JLCPCB Part # C23138
U34, U35, U36, U37: 74LS153; TSSOP-16_4.4x5mm_P0.65mm; Part Nr. 74HC153D; JLCPCB Part # C150159
U38: 74AHCT595; SOIC-16_3.9x9.9mm_P1.27mm; Part Nr. 74HC595D; JLCPCB Part # C5947

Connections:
+3.3VP: C35.1, U38.10 (~SRCLR), U38.16 (VCC); also elsewhere on the board
+3V3: C36.1, C37.1, C38.1, C39.1, U34.16 (VCC), U35.16 (VCC), U36.16 (VCC), U37.16 (VCC); also elsewhere on the board
/A0: R26.1, U37.7 (Za); also elsewhere on the board
/A1: R27.1, U37.9 (Zb); also elsewhere on the board
/B0: R24.1, U36.7 (Za); also elsewhere on the board
/B1: R25.1, U36.9 (Zb); also elsewhere on the board
/C0: R22.1, U35.7 (Za); also elsewhere on the board
/C1: R23.1, U35.9 (Zb); also elsewhere on the board
/CBpre_0: U34.6 (I0a), U35.6 (I0a), U36.6 (I0a), U37.6 (I0a); also elsewhere on the board
/CBpre_1: U34.10 (I0b), U34.11 (I1b), U35.10 (I0b), U35.11 (I1b), U36.10 (I0b), U36.11 (I1b), U37.10 (I0b), U37.11 (I1b); also elsewhere on the board
/CBw_0: U37.5 (I1a); also elsewhere on the board
/CBw_1: U36.5 (I1a); also elsewhere on the board
/CBw_2: U35.5 (I1a); also elsewhere on the board
/CBw_3: U34.5 (I1a); also elsewhere on the board
/D0: R20.1, U34.7 (Za); also elsewhere on the board
/D1: R21.1, U34.9 (Zb); also elsewhere on the board
/Input Selector/CBN_0: U34.3 (I3a), U37.4 (I2a); also elsewhere on the board
/Input Selector/CBN_1: U35.3 (I3a), U36.4 (I2a); also elsewhere on the board
/Input Selector/CBN_2: U35.4 (I2a), U36.3 (I3a); also elsewhere on the board
/Input Selector/CBN_3: U34.4 (I2a), U37.3 (I3a); also elsewhere on the board
/Input Selector/CBS_0: U34.13 (I3b), U37.12 (I2b); also elsewhere on the board
/Input Selector/CBS_1: U35.13 (I3b), U36.12 (I2b); also elsewhere on the board
/Input Selector/CBS_2: U35.12 (I2b), U36.13 (I3b); also elsewhere on the board
/Input Selector/CBS_3: U34.12 (I2b), U37.13 (I3b); also elsewhere on the board
/Input Selector/MISO: U38.9 (QH'); also elsewhere on the board
GND: C35.2, C36.2, C37.2, C38.2, C39.2, D17.1 (K), D18.1 (K), D19.1 (K), D20.1 (K), D21.1 (K), D22.1 (K), D23.1 (K), D24.1 (K), R20.2, R21.2, R22.2, R23.2, R24.2, R25.2, R26.2, R27.2, R29.2, R31.2, R33.2, R35.2, R37.2, R39.2, R41.2, R43.2, U34.1 (Ea), U34.8 (GND), U34.15 (Eb), U35.1 (Ea), U35.8 (GND), U35.15 (Eb), U36.1 (Ea), U36.8 (GND), U36.15 (Eb), U37.1 (Ea), U37.8 (GND), U37.15 (Eb), U38.8 (GND), U38.13 (~OE); also elsewhere on the board
LATCH: U38.12 (RCLK); also elsewhere on the board
MOSI: U38.14 (SER); also elsewhere on the board
unnamed: D17.2 (A), R28.2
unnamed: D18.2 (A), R30.2
unnamed: D19.2 (A), R32.2
unnamed: D20.2 (A), R34.2
unnamed: D21.2 (A), R36.2
unnamed: D22.2 (A), R38.2
unnamed: D23.2 (A), R40.2
unnamed: D24.2 (A), R42.2
SCLK: U38.11 (SRCLK); also elsewhere on the board
insel_a_0: R29.1, R42.1, U37.14 (S0), U38.15 (QA)
insel_a_1: R31.1, R40.1, U37.2 (S1), U38.1 (QB)
insel_b_0: R33.1, R38.1, U36.14 (S0), U38.2 (QC)
insel_b_1: R35.1, R36.1, U36.2 (S1), U38.3 (QD)
insel_c_0: R34.1, R37.1, U35.14 (S0), U38.4 (QE)
insel_c_1: R32.1, R39.1, U35.2 (S1), U38.5 (QF)
insel_d_0: R30.1, R41.1, U34.14 (S0), U38.6 (QG)
insel_d_1: R28.1, R43.1, U34.2 (S1), U38.7 (QH)

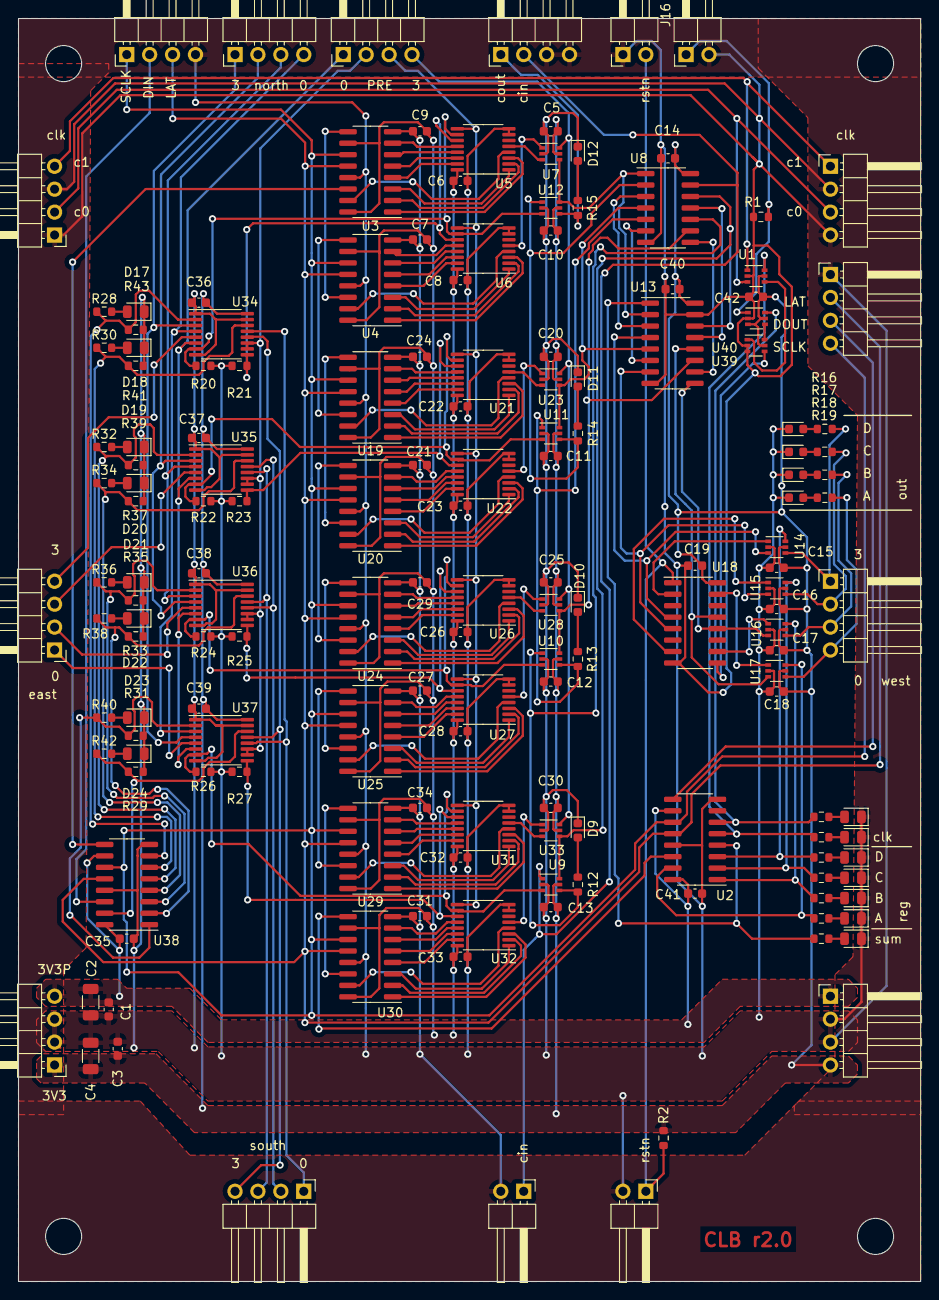
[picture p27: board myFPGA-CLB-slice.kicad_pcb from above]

Board: 2 copper layers, 100.0 x 140.0 mm, 162 parts (0 on the bottom side), 182 nets.

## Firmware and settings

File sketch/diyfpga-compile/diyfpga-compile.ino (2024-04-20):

/*******************************************************************************
 * @file        diyfpga.c
 * @brief       Rudimentary compiler that translates features from a struct into
 *              a binary bitstream for the FPGA
 * @details     
 * @version     
 * @author      Simon Burkhardt https://github.com/mnemocron
 * @date        2024.04
 * @see         https://github.com/mnemocron/my-discrete-fpga
*******************************************************************************/ 
#include <SPI.h>
#include <stdio.h>
#include "diyfpga.h"
#include "diyfpga_user.h"

/* SPI pinout
 * 13 -> SCLK
 * 12 -> MISO
 * 11 -> MOSI 
 */
#define LATCH_PIN 10
#define CLOCK_PIN 8
#define RST_PIN 9

#define CLOCK_HALF_PERIOD 50

FILE f_out;
int sput(char c, __attribute__((unused)) FILE* f) {return !Serial.write(c);}

fpga_t myfpga;  // fpga object: edit settings in diyfpga_user.h

void setup() {
  // todo: find out what the SPI is doing on reset. this could potentially be dangerous for the FPGA
  setup_printf();
  setup_gpio();

  /* Program the FPGA functionality in myfpga_user.cpp */
  diyfpga_setup(); 
  create_bitstream(&myfpga);
  program_bitstream(myfpga.bitstream, N_BYTES_BITSTREAM);


  for(int i=0; i<N_BYTES_SLICE; i++){
    printf("%02X\n", myfpga.slice[0][0].bitstream[i]);
  }
}

void loop() {
  do_clk();
}

void setup_printf(){
  Serial.begin(9600);
  fdev_setup_stream(&f_out, sput, nullptr, _FDEV_SETUP_WRITE); // cf https://www.nongnu.org/avr-libc/user-manual/group__avr__stdio.html#gaf41f158c022cbb6203ccd87d27301226
  stdout = &f_out;
}

void setup_gpio(){
  pinMode(LATCH_PIN, OUTPUT);
  digitalWrite(LATCH_PIN, LOW);
  pinMode(CLOCK_PIN, OUTPUT);
  pinMode(RST_PIN, OUTPUT);
  pinMode(2, OUTPUT);
  pinMode(3, OUTPUT);
  pinMode(4, OUTPUT);
  pinMode(5, OUTPUT);
  pinMode(A0, INPUT);
  pinMode(A1, INPUT);
  pinMode(A2, INPUT);
  pinMode(A3, INPUT);

  SPI.begin();
  SPI.setBitOrder(LSBFIRST);
}

void program_bitstream(char* bin, int len){
  digitalWrite(RST_PIN, LOW);

  for(int i=0; i<len; i++){
    SPI.transfer(*bin++);
  }
  digitalWrite(LATCH_PIN, HIGH);
  delay(1);
  digitalWrite(LATCH_PIN, LOW);

  delay(50);
  digitalWrite(RST_PIN, HIGH);
  delay(50);
}

void do_clk(){
  digitalWrite(CLOCK_PIN, LOW);
  delay(CLOCK_HALF_PERIOD);
  digitalWrite(CLOCK_PIN, HIGH);
  delay(CLOCK_HALF_PERIOD);
}

int rd4(){
  int val = 0;
  if(digitalRead(A0))
    val |= (1<<0);
  if(digitalRead(A1))
    val |= (1<<1);
  if(digitalRead(A2))
    val |= (1<<2);
  if(digitalRead(A3))
    val |= (1<<3);
  return val;
}

void wrt4(int val){

  if( (val & 1) )
    digitalWrite(2, HIGH);
  else
    digitalWrite(2, LOW);

  if( (val & 2) )
    digitalWrite(3, HIGH);
  else
    digitalWrite(3, LOW);

  if( (val & 4) )
    digitalWrite(4, HIGH);
  else
    digitalWrite(4, LOW);

  if( (val & 8) )
    digitalWrite(5, HIGH);
  else
    digitalWrite(5, LOW);
}

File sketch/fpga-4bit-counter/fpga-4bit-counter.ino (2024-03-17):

ar
#include <SPI.h>
#include <stdio.h>

#define LATCH_PIN 10
#define CLOCK_PIN 7

#define CLB_BYTES (10)
#define BITS_CONFIGURED (4+8+8+8+8)
#define CLB_OFFSET (8)
#define CLOCK_HALF_PERIOD (250)

char bitstream[CLB_BYTES];
char conf_bits[BITS_CONFIGURED] = {/*reg*/15,14,13,12, /*LUT_A*/24,25,26,27,28,29,30,31, /*LUT_B*/36,37,38,39,40,41,42,43, /*LUT_C*/50,51,52,53,56,57,60,61, /*LUT_D*/65,66,68,70,72,74,76,78};

FILE f_out;
int sput(char c, __attribute__((unused)) FILE* f) {return !Serial.write(c);}

void setup() {
  pinMode(LATCH_PIN, OUTPUT);
  digitalWrite(LATCH_PIN, LOW);
  pinMode(CLOCK_PIN, OUTPUT);
  pinMode(2, OUTPUT);
  pinMode(3, OUTPUT);
  pinMode(4, OUTPUT);
  pinMode(5, OUTPUT);
  pinMode(A0, INPUT);
  pinMode(A1, INPUT);
  pinMode(A2, INPUT);
  pinMode(A3, INPUT);
  
  Serial.begin(9600);
  fdev_setup_stream(&f_out, sput, nullptr, _FDEV_SETUP_WRITE); // cf https://www.nongnu.org/avr-libc/user-manual/group__avr__stdio.html#gaf41f158c022cbb6203ccd87d27301226
  stdout = &f_out;

  SPI.begin();
  SPI.setBitOrder(LSBFIRST);
  prg_bitstream();

}

void loop() {
  do_clk();
}

void test_lut(int offset){
  for(int i=0; i<16; i++){
    conf_bits[1] = (16*(offset+1))+i;
    prg_bitstream();
    printf(" %04x |", (1<<i));
    for(int j=0; j<16; j++){
      wrt4(j);
      do_clk();
      int val = rd4();
      if( (val & (1<<offset)) )
        Serial.print(" 1 ");
      else
        Serial.print(" . ");
    }
    Serial.println("");
  }
  Serial.println("");
}

void prg_bitstream(){
  for(int i=0; i<CLB_BYTES; i++)
    bitstream[i] = 0;
  for(int i=0; i<BITS_CONFIGURED; i++){
      char bt = conf_bits[i] - CLB_OFFSET;
      bitstream[bt/8] |= (1 << (bt%8));
      if(i == 1)
        printf("(%d)", conf_bits[i]);
  }
  for(int i=0; i<CLB_BYTES; i++){
    SPI.transfer(bitstream[i]);
  }
  digitalWrite(LATCH_PIN, HIGH);
  delay(1);
  digitalWrite(LATCH_PIN, LOW);
}

void do_clk(){
  digitalWrite(CLOCK_PIN, LOW);
  delay(CLOCK_HALF_PERIOD);
  digitalWrite(CLOCK_PIN, HIGH);
  delay(CLOCK_HALF_PERIOD);
}

int rd4(){
  int val = 0;
  if(digitalRead(A0))
    val |= (1<<0);
  if(digitalRead(A1))
    val |= (1<<1);
  if(digitalRead(A2))
    val |= (1<<2);
  if(digitalRead(A3))
    val |= (1<<3);
  return val;
}

void wrt4(int val){

  if( (val & 1) )
    digitalWrite(2, HIGH);
  else
    digitalWrite(2, LOW);

  if( (val & 2) )
    digitalWrite(3, HIGH);
  else
    digitalWrite(3, LOW);

  if( (val & 4) )
    digitalWrite(4, HIGH);
  else
    digitalWrite(4, LOW);

  if( (val & 8) )
    digitalWrite(5, HIGH);
  else
    digitalWrite(5, LOW);
}

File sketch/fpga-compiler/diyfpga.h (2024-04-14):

/*******************************************************************************
 * @file        diyfpga.h
 * @brief       Rudimentary compiler that translates features from a struct into
 *              a binary bitstream for the FPGA
 * @details     
 * @version     
 * @author      Simon Burkhardt https://github.com/mnemocron
 * @date        2024.04
 * @see         https://github.com/mnemocron/my-discrete-fpga
*******************************************************************************/
#include <stdbool.h>
#include <stdint.h>
#include "diyfpga_user.h"

#ifndef MY_FPGA_H
#define	MY_FPGA_H

#define N_BYTES_CLB (10)
#define N_BYTES_CBV (1)
#define N_BYTES_CBH (2)
#define N_BYTES_CSW (4)
#define N_BYTES_SLICE (N_BYTES_CLB + N_BYTES_CBV + N_BYTES_CBH + N_BYTES_CSW)

typedef enum {
  GND = 0,
  VCC = 1,
  BUS_5 = 2,
  BUS_4 = 3,
  BUS_3 = 4,
  BUS_2 = 5,
  BUS_1 = 6,
  BUS_0 = 7
} cbh_select_t;

typedef struct {
  cbh_select_t sel[4];
  bool ce;
  bool cin;
  bool cout_n;
  bool cout_s;
} cbh_t;

typedef struct {
  bool bus[4];
  bool bus_0_to_5;
  bool bus_2_to_5;
  bool bus_1_to_4;
  bool bus_3_to_4;
} cbv_t;

typedef struct {
  bool north[6];
  bool south[6];
  bool east[6];
  bool west[6];
  bool xp[6];
  bool ns4_to_ew5;
  bool ns5_to_ew4;
} sw_t;

typedef enum {
  PRE = 0,
  LUT_EXPAND = 1,
  SUM_INPUT = 2,
  SUM_INPUT_REVERSED = 3
} insel_t;

typedef struct {
  bool reg[4];
  bool sum;
  int clk_sel;
  bool clk_en;
  uint16_t lut[4];
  insel_t in_mux[4];
} clb_t;

typedef struct {
  int pos_x;
  int pos_y;
  clb_t clb;
  cbv_t cbv;
  cbh_t cbh;
  sw_t  sw;
  char bitstream[N_BYTES_SLICE];
} slice_t;

typedef struct {
  slice_t slice[N_SLICE_X][N_SLICE_Y];
  int Nx;
  int Ny;
} fpga_t;

int create_bitstream(fpga_t* fpga);

#endif	/* MY_FPGA_H */

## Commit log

2023-09-04 added kicad to gitignore
2023-09-04 VHDL sim of CLB slice successful\nrequires assert statements\nsum and carry chain not yet tested
2023-09-04 added kicad CLB (wip)
    [4to1_input_mux.kicad_sch, carry_chain.kicad_sch, d-latch-register.kicad_sch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]
2023-09-05 fixed kicad names, updated architecure, started CBv
    [carry_chain.kicad_sch, d-latch-register.kicad_sch, input_selector.kicad_sch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]
2023-09-06 kicad -> pcb started
    [carry_chain.kicad_sch, d-latch-register.kicad_sch, input_selector.kicad_sch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]
2023-09-07 new crosspoint helper IP, started Switchbox
2023-09-07 kicad: picked JLC parts, fixed routing to match VHDL, started layouting
    [carry_chain.kicad_sch, d-latch-register.kicad_sch, input_selector.kicad_sch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]
2023-10-28 restart PCB layout
    [input_selector.kicad_sch, lut4.kicad_sch, myFPGA-CLB-slice.kicad_pcb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]
2023-10-28 added toggle_bit test case for entire slice\nfound some bugs with bitstream order
2023-10-29 progress in pcb of CLB
    [d-latch-register.kicad_sch, input_selector.kicad_sch, myFPGA-CLB-slice.kicad_pcb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]
2023-10-30 2 layer pcb for clb seems complete (awaits review)
    [myFPGA-CLB-slice.kicad_pcb, myFPGA-CLB-slice.kicad_sch]
2023-10-31 new approach to transistor level simulation for xpoint switch seems to work
2023-10-31 new xpoint switch seems to work
2023-10-31 new bitstream documentation (LUT fields are wrong)
    [bitstream_doc.xlsx]
2023-11-02 several bugs in bitstream occurred - configuration bits in VHDL model do not match with PCB - configuration bits in VHDL don't match with excel sheet - set_reg_* bits don't map correctly - LUT bits d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
    let's just redo the entire bitstream documentation.
    take PCB as reference, adapt to VHDL, document in excel
    [bitstream_doc.xlsx]
2023-11-05 IT WORKS! first successful bit toggle simulation using all 4 tile elements - fixed bitstream order issue - fixed delta loop problem - simulation is ready for bitstreams
    [bitstream_doc.xlsx]
2023-11-05 fixed a footprint
    [carry_chain.kicad_sch, input_selector.kicad_sch, myFPGA-CLB-slice.kicad_pcb]
2023-11-06 fixed a footprint, changed to 2 Layer stackup
    [carry_chain.kicad_sch, input_selector.kicad_sch, myFPGA-CLB-slice.kicad_pcb]
2023-12-04 add kicad gerber outputs to gitignore
2023-12-04 gitignore fix
    [input_selector.kicad_sch, lut4.kicad_sch, myFPGA-CLB-slice.kicad_pcb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]
2023-12-28 generate new images
    [lut_truth_table.xlsx]
2023-12-28 experiment with assembled PCB
2024-01-02 started kicad projects for interconnect
    [mcFPGA-SW-box.kicad_pcb, mcFPGA-SW-box.kicad_sch, myFPGA-CBv.kicad_pcb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]
2024-01-02 update bitstream documentation
    [bitstream_doc.xlsx, lut_truth_table.xlsx]
2024-01-02 start layout of SW box
    [mcFPGA-SW-box.kicad_pcb, mcFPGA-SW-box.kicad_sch]
2024-01-03 SWbox layout nearly complete
    [mcFPGA-SW-box.kicad_pcb, mcFPGA-SW-box.kicad_sch, myFPGA-CLB-slice.kicad_pcb]
2024-01-04 verified matching bitstream between PCB and VHDL
2024-01-06 sw box layout almost complete
    [mcFPGA-SW-box.kicad_pcb, mcFPGA-SW-box.kicad_sch]
2024-01-08 more kicad layouts
    [carry_chain.kicad_sch, d-latch-register.kicad_sch, input_selector.kicad_sch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]
2024-01-10 more kicad layouts 2.
    [myFPGA-CBv.kicad_pcb, myFPGA-CBv.kicad_sch, myFPGA-SW-box.kicad_pcb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]
2024-01-15 CLB requires rev.2
    [myFPGA-CLB-slice.kicad_pcb, myFPGA-CLB-slice.kicad_sch]
2024-01-17 CLB slice rev. 2.0 - fix aresetn pullup instead of pulldown - new feature: clock enable - fixes S0 and S1 flipped
    [myFPGA-CLB-slice.kicad_pcb, myFPGA-CLB-slice.kicad_sch, myFPGA-SW-box.kicad_sch]
2024-01-18 start new feature CE
    [myFPGA-CBh.kicad_pcb, myFPGA-CBh.kicad_sch]
2024-02-13 PCB renders
2024-02-20 found more bugs
    [bitstream_doc.xlsx, myFPGA-CBh.kicad_pcb, myFPGA-CBh.kicad_sch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]
2024-02-25 fix wrong bitstream order
    [bitstream_doc.xlsx]
2024-03-04 updated VHDL model to match PCB
    [bitstream_doc.xlsx]
2024-03-08 fixed CE throughout simulation
    [bitstream_doc.xlsx, lut_truth_table.xlsx]
2024-03-14 remove final occurrences of the word "prio"
    [bitstream_doc.xlsx, lut_truth_table.xlsx]
2024-04-13 built a working "compiler" in C for Arduino
    [bitstream_doc.xlsx]
2024-04-14 fix bugs in compiler, add another slice -> working :D
    [diyfpga-compile.ino, diyfpga.h]
2024-04-17 updated images for blogpost
    [bitstream_doc.xlsx, lut_truth_table.xlsx]
2024-04-20 ready for first release - fixed Arduino compiler - more documentation - tested SUM mode on 3 Tiles (physical PCB)
    [lut_truth_table.xlsx]
